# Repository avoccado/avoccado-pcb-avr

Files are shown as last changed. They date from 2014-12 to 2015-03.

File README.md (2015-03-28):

Avoccado° PCB layouts and schematics
================

**Most recent version: Avoccado° Felina**

This repository contains the source files of the PCBs for Avoccado° controllers equipped with AVR micro controllers.

There are different PCBs, some with more than one revision. Check the commit log for the most recent development version.

 - Alpha 1 (A1): 8/10 mil width/spacing, 2 sided, components on one side, full size rectangular board a la Arduino Nano / Pro Mini with female micro USB 2.0 and LiPo charger
 - Kane: 8/8 mil, small square board without LiPo charger, components on both sides, good as a tiny RX (receiver) node.
 - Yolandi: 8/8 mil, never tested
 - Nora 1: square board, about one square inch, IRQ from NRF24 routed to MCU
 - Nora 2: same as Nora 1 with IRQ from NRF24 and MPU6050 routed to MCU
 - Faye: updated Nora 2 with voltage divider to sense battery voltage and derive SOC (state of charge), added optional micro USB SMD socket on bottom layer, optionally less part diversity count as R_charge-program can be set with two serialised 1K 0402 resistors. Faye has got an equal 100 mil grid for every pin header and test point.
 - Felina: Features like Faye, without 0402 R_charge-program, non-square footprint, with MPU6050 QFN on board (optional), USB SMD on bottom layer
 - Gin: Board layout smaller than one NRF24L01 PCB module, features AtMega328 QFN + MPU6050 QFN. Not possible to hand solder, very small overall footprint. USB connector only passive (for charging)

Alpha 1 (A1):
----------------
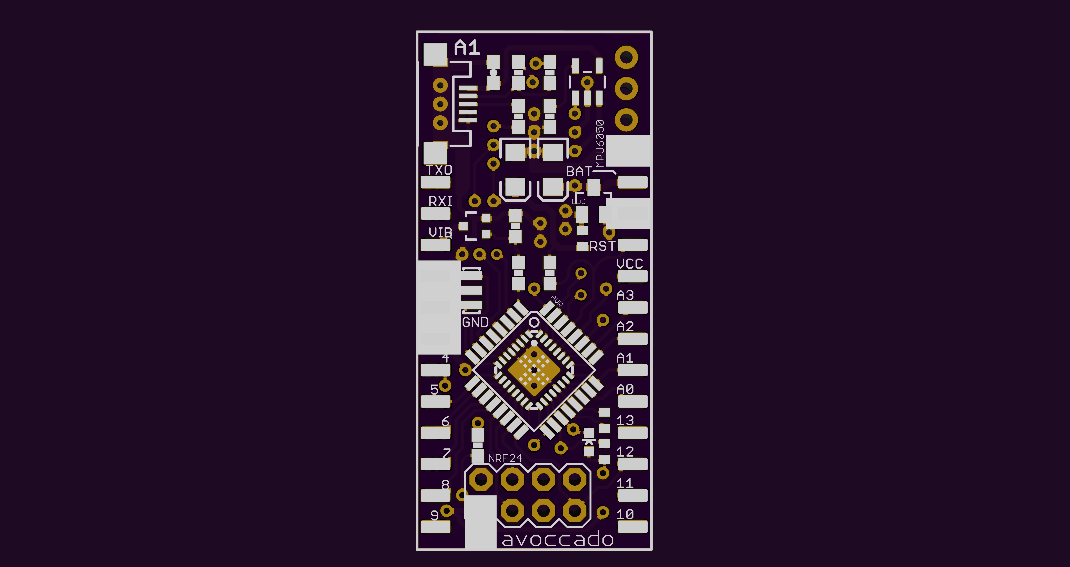
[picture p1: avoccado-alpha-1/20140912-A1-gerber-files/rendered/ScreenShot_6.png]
IMG board screenshot

USB bootloader option to update the firmware if the 68R resistors are populated. The USB data lines connect to D2 and D7.
There is a 2K pullup to 3.3V at the D- USB data line, no zener diodes to limit the voltage at the data lines because the MCU runs at USB compliant 3.3V VCC, see vUSB recommendations here: http://vusb.wikidot.com/hardware

Kane
----------------
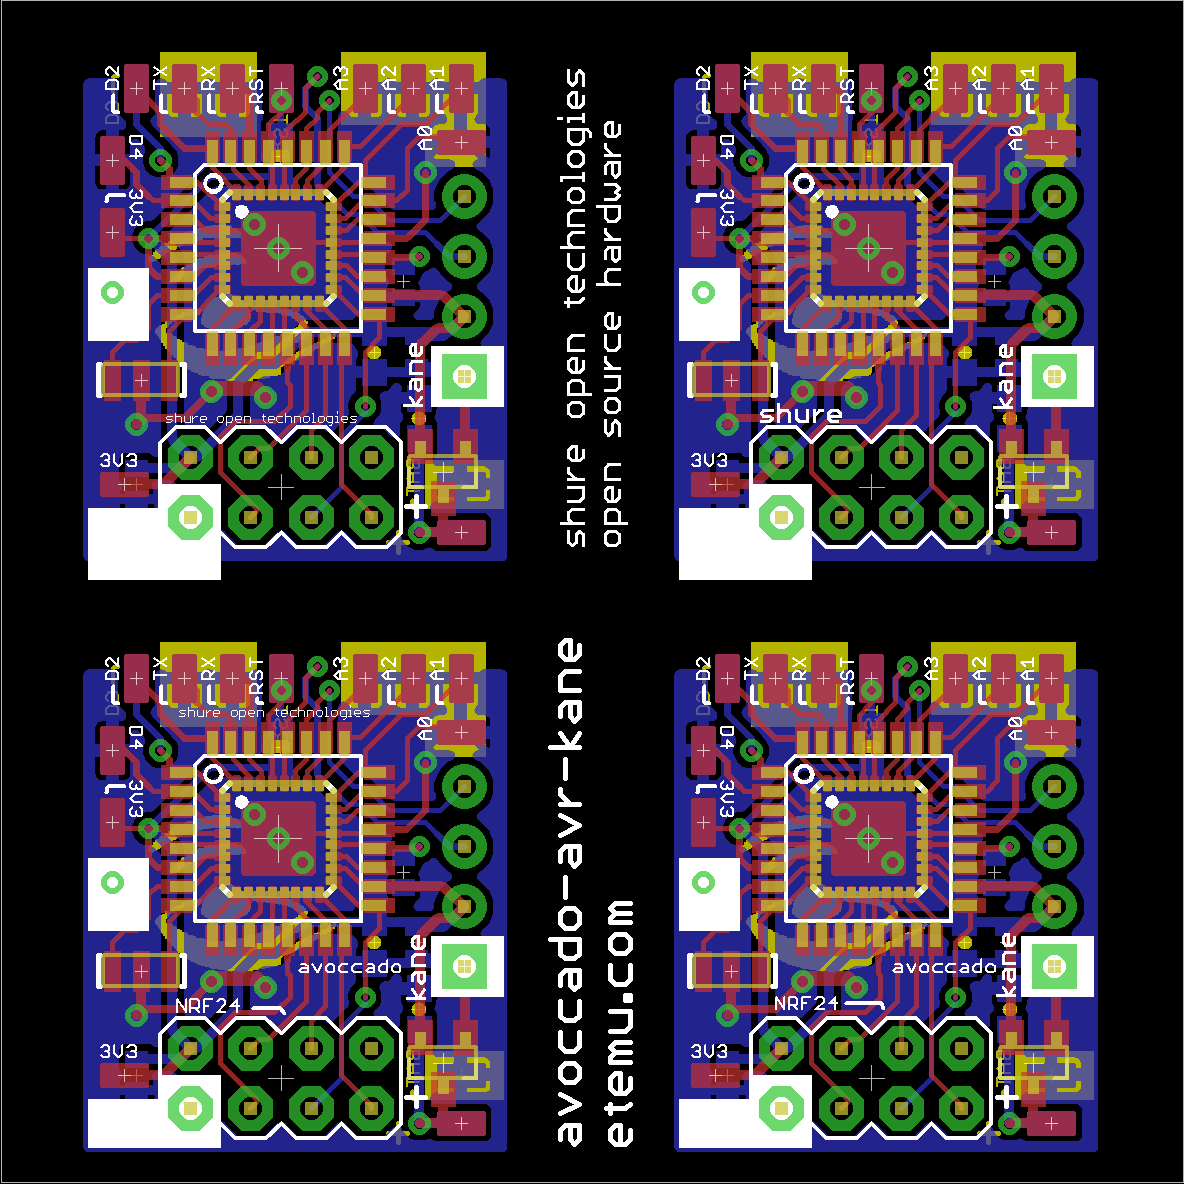
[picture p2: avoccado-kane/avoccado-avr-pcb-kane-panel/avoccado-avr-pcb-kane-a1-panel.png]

Smallest version when MPU6050 board not used. Hard to populate due to parts on both sides. Good for tiny receiver nodes, can be hidden in the E27 socket of a light bulb, wall socket..

Nora
----------------
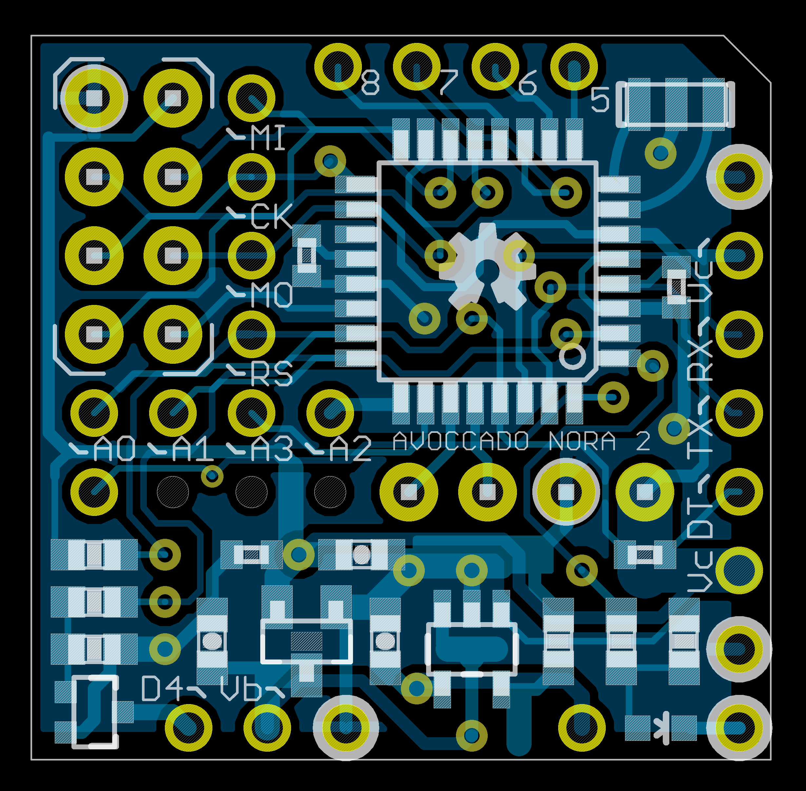
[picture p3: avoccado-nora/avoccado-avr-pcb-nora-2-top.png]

Notes and ideas: No cinsistent 100 mil grid with all headers at the moment
Plated half holes are nice for SMD piggybacking the hole board. Mind the test points and exposed pads on the bottom.

Faye
----------------
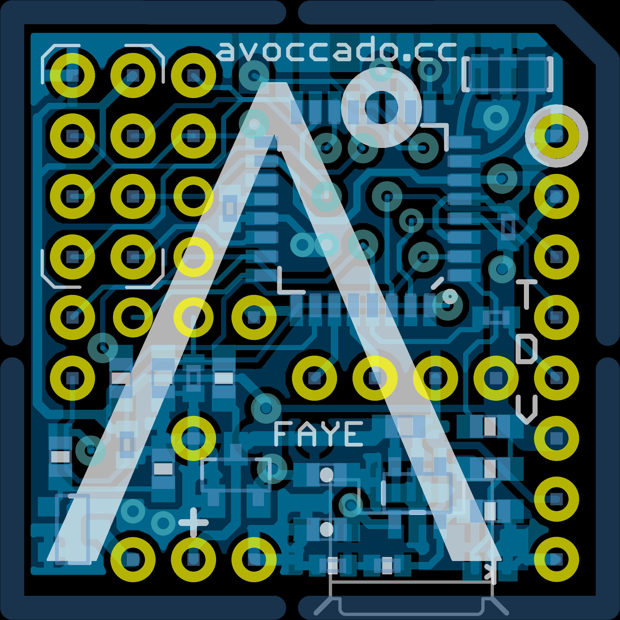
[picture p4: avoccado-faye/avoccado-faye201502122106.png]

Consistent 100 mil grid for all pin headers, additional test points (all conforming the 100 mil grid).
Tighter spacing with 0402 parts now close to the MCU and border of the board.
Battery voltage fed into ADC portpin through high impedance voltage divider to estimate SOC with the MCU.
Optional micro USB socket on the bottom. Data lines not used as of now due to routing constraints, only used for power and charging LiPo batteries.

Felina
----------------
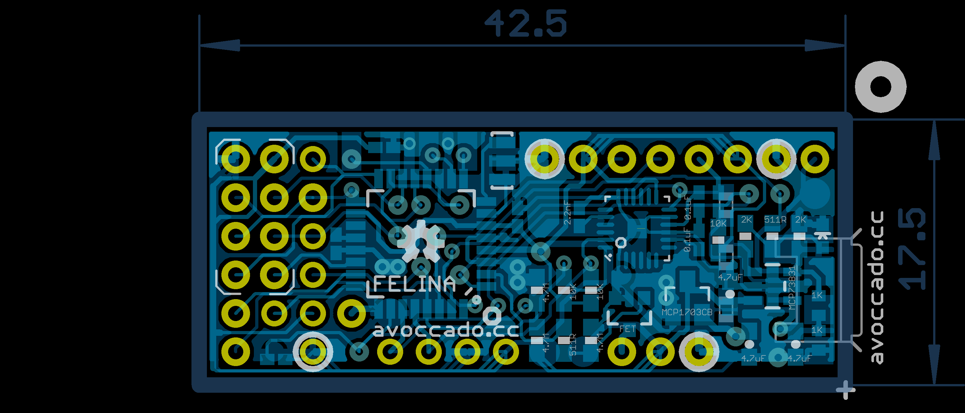
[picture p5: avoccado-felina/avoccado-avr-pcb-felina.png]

InvenSense MPU6000 / MPU6050 QFN package on board instead of peripheral daughter board. Header for peripheral board still available. Slim rectangular design, slightly longer due to additional parts for onboard MPU, thus only 10 PCBs per panel instead of the usual 16.
Battery voltage fed into ADC portpin through high impedance voltage divider to estimate SOC with the MCU.
Optional: Micro USB female on bottom side for charging
Optional: V-USB components with 2K pullup on D- to enable USB firmware usage. (needs airwire for one data line) 
Attention: V-USB uses same D2 IRQ line as MPU6050.
Consistent 100 mil grid for all pin headers, additional test points, SMD pad for vibration motor output.

Gin
----------------
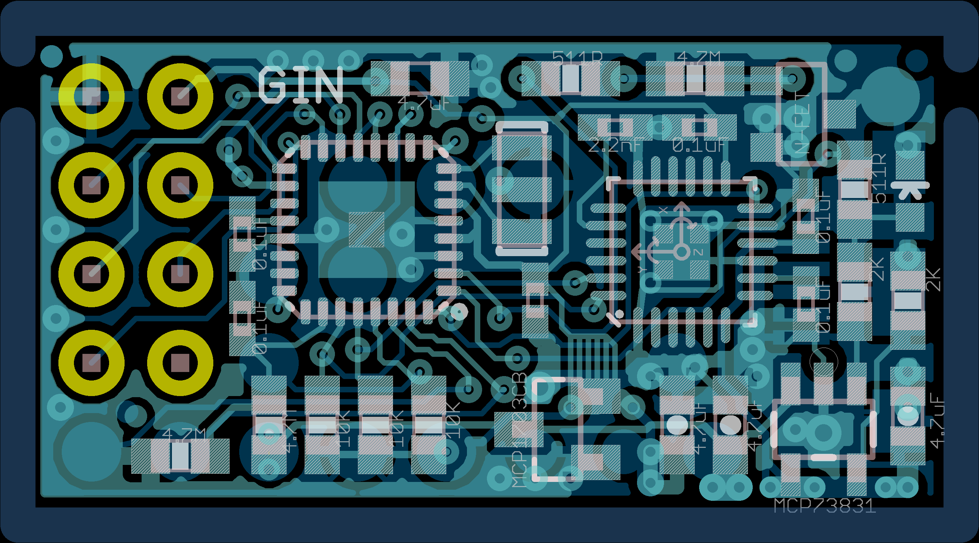
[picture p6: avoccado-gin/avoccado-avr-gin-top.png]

InvenSense MPU6050 QFN package, Atmel AtMega328p QFN package, very small overall footprint, smaller than a NRF24 module. No seperate ICSP header, flashing only via test points and the NRF24 connector. No DTR reset latch with capacitor.
Consistent 100 mil grid for all headers and test points. 

Panels 
----------------
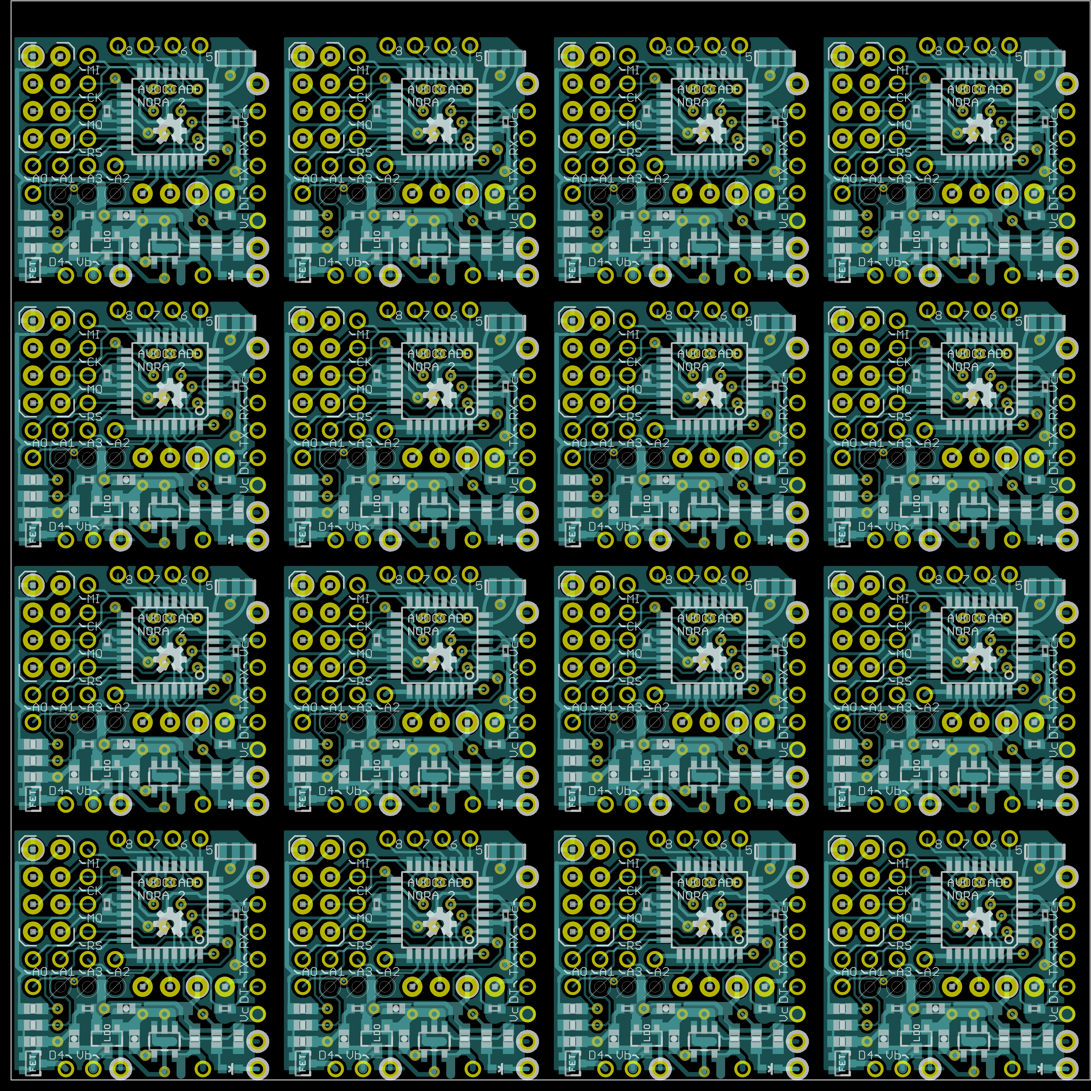
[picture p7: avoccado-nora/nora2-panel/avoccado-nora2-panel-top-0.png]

Boards are either panelized to 50 x 50 mm² or 100 x 100 mm² because my test jig can hold those two sizes. PCBs are usually placed on a 25 mm grid - that is slightly below one inch (25.4 mm).

Test jigs
----------------
Nora 2 test jig is compatible with Nora 1 and Nora 2
See separate repository for test jig assemblies

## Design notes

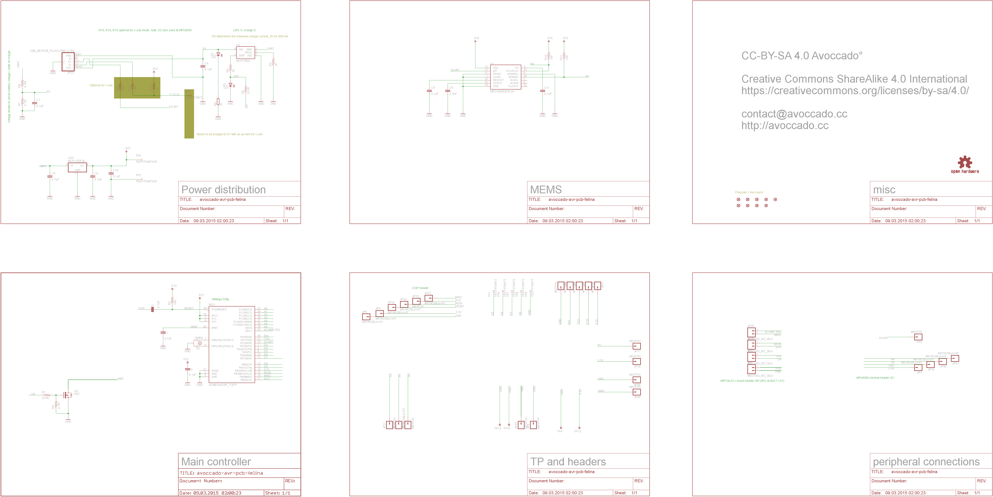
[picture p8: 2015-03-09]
avoccado-felina/avoccado-avr-pcb-felina-schematic.png

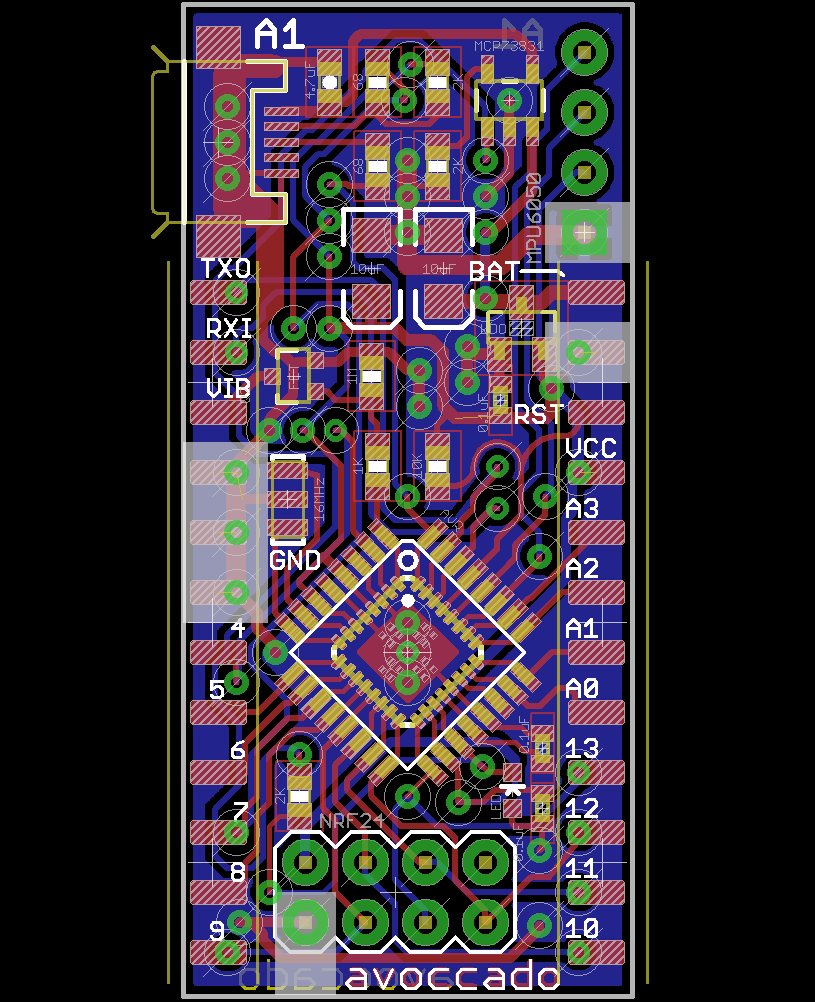
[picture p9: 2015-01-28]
avoccado-alpha-1/avoccado-avr-pcb.png

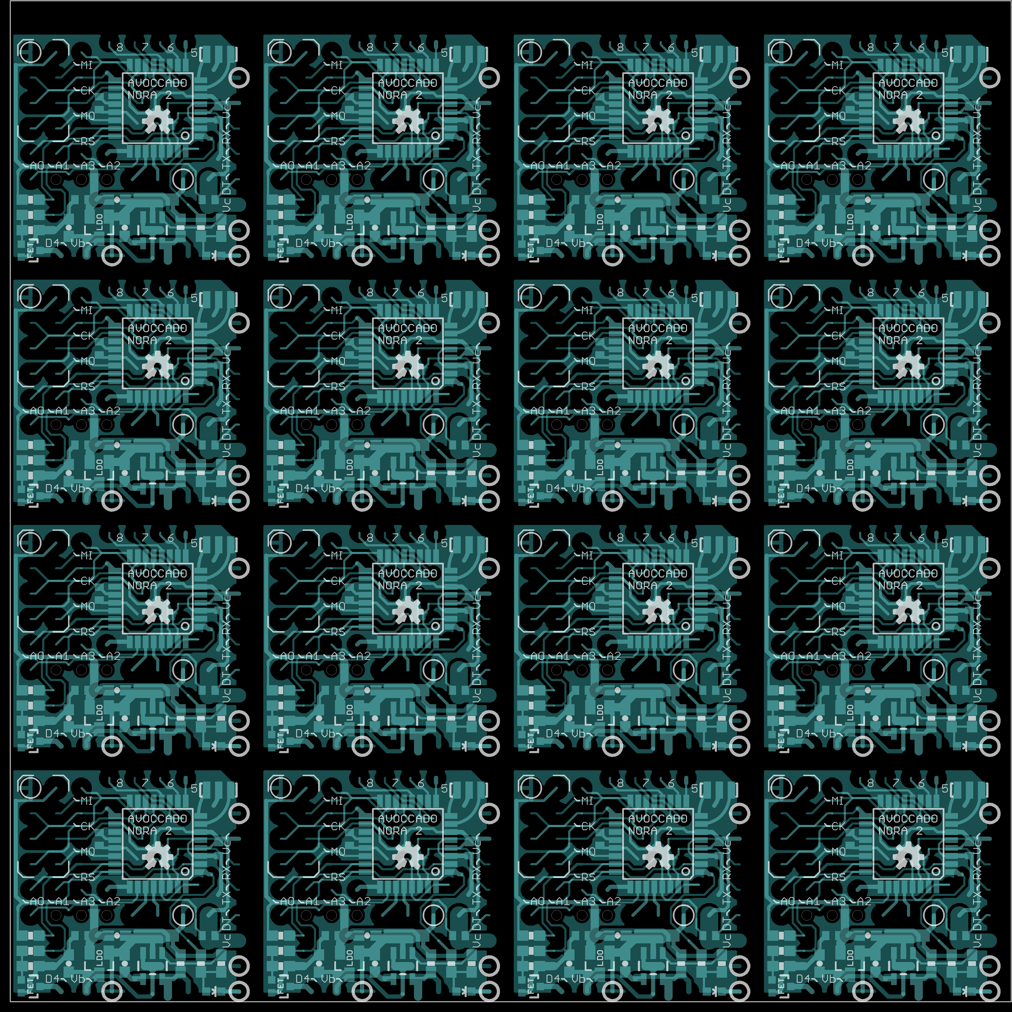
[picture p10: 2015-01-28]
avoccado-nora/nora2-panel/avoccado-nora2-panel-top-4.png

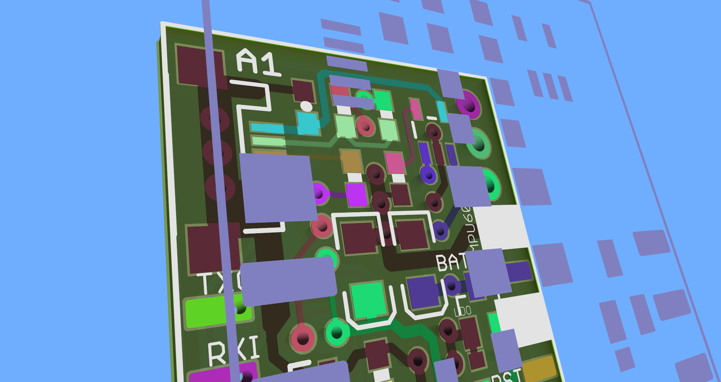
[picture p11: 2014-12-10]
avoccado-alpha-1/20140912-A1-gerber-files/rendered/ScreenShot_5.png

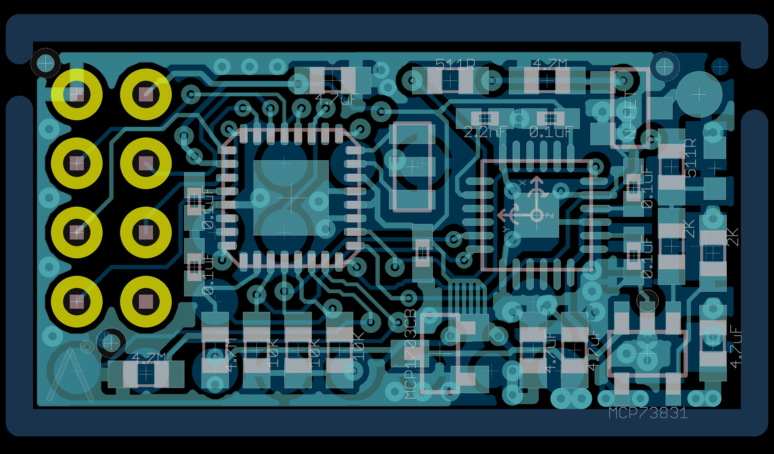
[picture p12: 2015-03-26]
avoccado-gin/avoccado-avr-gin-top-bot.png

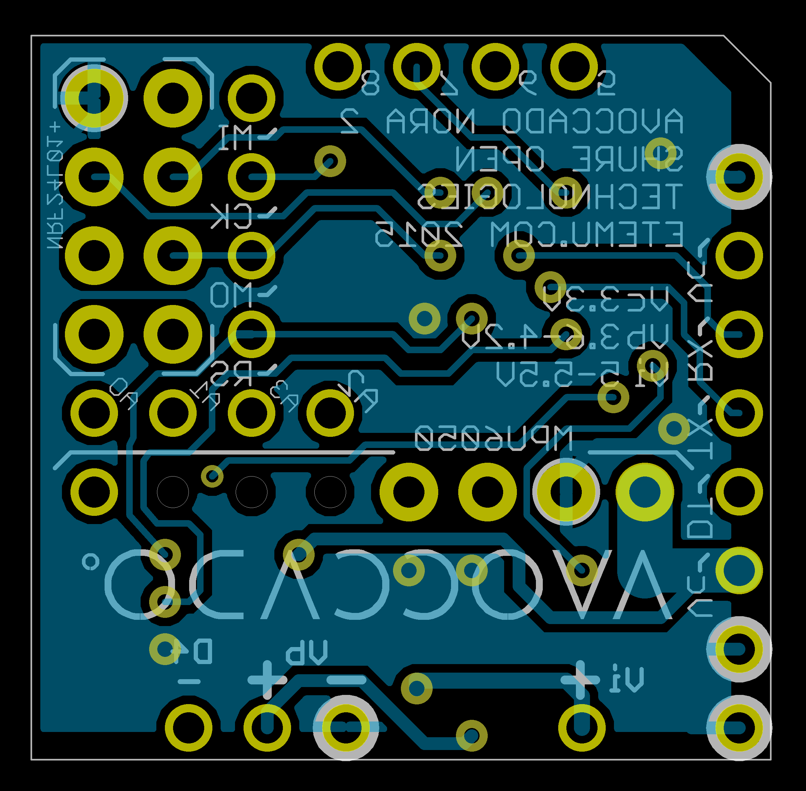
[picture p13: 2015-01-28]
avoccado-nora/avoccado-avr-pcb-nora-2-bot.png

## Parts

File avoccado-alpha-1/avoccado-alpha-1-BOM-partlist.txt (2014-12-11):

Partlist

Exported from avoccado-avr-pcb.brd at 12/8/2014 3:34:41 PM

Assembly variant: Full

Part     Value                   Package       Position (mil)        Orientation
                                               
C1       0.1uF                   C0402         (575 425)             R270
C3       0.1uF                   C0402         (575 325)             R90
C4       4.7uF                   0603-CAP      (220 1535)            R90
C10      0.1uF                   C0402         (505 1005)            R90
C13      10uF                    EIA3216       (290 1225)            R270
C19      10uF                    EIA3216       (410 1225)            R270
D1       CHARGE LED              LED-0603      (525 355)             R0
IC1      MCP1703CB               SOT23         (540 1125)            R0
JP1      4x1 header female       1X04_LOCK     (650 1285)            R90
NRF24    4X2 header female       2X4           (330 185)             R0
Q1       16MHz                   RESONATOR-SMD (150 840)             R90
Q2       MOSFET-NCHANNEL2N7002PW SOT323        (160 1045)            R90
R1       1K                      0603-RES      (300 895)             R90
R2       10K                     0603-RES      (400 895)             R90
R3       2K                      0603-RES      (400 1395)            R90
R4       2K                      0603-RES      (170 345)             R90
R5       1M                      0603-RES      (290 1045)            R270
R6       68                      0603-RES      (300 1535)            R90
R7       68                      0603-RES      (300 1395)            R270
R8       2K                      0603-RES      (400 1535)            R90
U2       MCP73831                SOT23-5       (520 1505)            R0
X1       Micro USB               USB-MICROB    (50 1435)             R270

and either of the following two:
IC5      ATMEGA328P-20MU         MLF32         (350 585)             R315
U1       ATMEGA328P              TQFP32-08     (350 585)             R315

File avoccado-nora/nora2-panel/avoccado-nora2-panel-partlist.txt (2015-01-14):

Partlist

Exported from avoccado-nora2-panel-100x100.brd

EAGLE Version 7.2.0 Copyright (c) 1988-2014 CadSoft

Assembly variant: 

Part     Value           Package       Library               Position (inch)       Orientation

AVR      ATMEGA328P      TQFP32-08     SparkFun-DigitalIC    (0.58 0.62031496)     R180
AVR1     ATMEGA328P      TQFP32-08     SparkFun-DigitalIC    (1.56425197 0.62031496) R180
AVR2     ATMEGA328P      TQFP32-08     SparkFun-DigitalIC    (0.58 1.58488189)     R180
AVR3     ATMEGA328P      TQFP32-08     SparkFun-DigitalIC    (1.56425197 1.58488189) R180
AVR4     ATMEGA328P      TQFP32-08     SparkFun-DigitalIC    (2.54850394 0.62031496) R180
AVR5     ATMEGA328P      TQFP32-08     SparkFun-DigitalIC    (3.53275591 0.62031496) R180
AVR6     ATMEGA328P      TQFP32-08     SparkFun-DigitalIC    (2.54850394 1.58488189) R180
AVR7     ATMEGA328P      TQFP32-08     SparkFun-DigitalIC    (3.53275591 1.58488189) R180
AVR8     ATMEGA328P      TQFP32-08     SparkFun-DigitalIC    (0.58 2.54944882)     R180
AVR9     ATMEGA328P      TQFP32-08     SparkFun-DigitalIC    (1.56425197 2.54944882) R180
AVR10    ATMEGA328P      TQFP32-08     SparkFun-DigitalIC    (0.58 3.51401575)     R180
AVR11    ATMEGA328P      TQFP32-08     SparkFun-DigitalIC    (1.56425197 3.51401575) R180
AVR12    ATMEGA328P      TQFP32-08     SparkFun-DigitalIC    (2.54850394 2.54944882) R180
AVR13    ATMEGA328P      TQFP32-08     SparkFun-DigitalIC    (3.53275591 2.54944882) R180
AVR14    ATMEGA328P      TQFP32-08     SparkFun-DigitalIC    (2.54850394 3.51401575) R180
AVR15    ATMEGA328P      TQFP32-08     SparkFun-DigitalIC    (3.53275591 3.51401575) R180
C1       0.1uF           C0402         SparkFun              (0.35 0.64031496)     R90
C2       0.1uF           C0402         SparkFun              (0.78 0.26031496)     R0
C3       0.1uF           C0402         SparkFun              (0.82 0.60031496)     R90
C4       4.7uF           0603-CAP      SparkFun-Capacitors   (0.45 0.15031496)     R90
C5       4.7uF           0603-CAP      SparkFun-Capacitors   (0.23 0.15031496)     R90
C6       4.7uF           0603-CAP      SparkFun-Capacitors   (0.42 0.26031496)     R0
C7       0.1uF           C0402         SparkFun              (1.26425197 0.26031496) R180
C8       0.1uF           C0402         SparkFun              (1.80425197 0.60031496) R90
C9       0.1uF           C0402         SparkFun              (1.33425197 0.64031496) R90
C10      0.1uF           C0402         SparkFun              (0.28 0.26031496)     R180
C11      4.7uF           0603-CAP      SparkFun-Capacitors   (1.43425197 0.15031496) R90
C12      0.1uF           C0402         SparkFun              (1.76425197 0.26031496) R0
C13      4.7uF           0603-CAP      SparkFun-Capacitors   (1.21425197 0.15031496) R90
C14      4.7uF           0603-CAP      SparkFun-Capacitors   (1.40425197 0.26031496) R0
C15      0.1uF           C0402         SparkFun              (0.28 1.22488189)     R180
C16      0.1uF           C0402         SparkFun              (0.82 1.56488189)     R90
C17      0.1uF           C0402         SparkFun              (0.35 1.60488189)     R90
C18      4.7uF           0603-CAP      SparkFun-Capacitors   (0.45 1.11488189)     R90
C19      0.1uF           C0402         SparkFun              (0.78 1.22488189)     R0
C20      4.7uF           0603-CAP      SparkFun-Capacitors   (0.23 1.11488189)     R90
C21      4.7uF           0603-CAP      SparkFun-Capacitors   (0.42 1.22488189)     R0
C22      0.1uF           C0402         SparkFun              (1.26425197 1.22488189) R180
C23      0.1uF           C0402         SparkFun              (1.80425197 1.56488189) R90
C24      0.1uF           C0402         SparkFun              (1.33425197 1.60488189) R90
C25      4.7uF           0603-CAP      SparkFun-Capacitors   (1.43425197 1.11488189) R90
C26      0.1uF           C0402         SparkFun              (1.76425197 1.22488189) R0
C27      4.7uF           0603-CAP      SparkFun-Capacitors   (1.21425197 1.11488189) R90
C28      4.7uF           0603-CAP      SparkFun-Capacitors   (1.40425197 1.22488189) R0
C29      0.1uF           C0402         SparkFun              (2.24850394 0.26031496) R180
C30      0.1uF           C0402         SparkFun              (2.78850394 0.60031496) R90
C31      0.1uF           C0402         SparkFun              (2.31850394 0.64031496) R90
C32      4.7uF           0603-CAP      SparkFun-Capacitors   (2.41850394 0.15031496) R90
C33      0.1uF           C0402         SparkFun              (2.74850394 0.26031496) R0
C34      4.7uF           0603-CAP      SparkFun-Capacitors   (2.19850394 0.15031496) R90
C35      4.7uF           0603-CAP      SparkFun-Capacitors   (2.38850394 0.26031496) R0
C36      0.1uF           C0402         SparkFun              (3.23275591 0.26031496) R180
C37      0.1uF           C0402         SparkFun              (3.77275591 0.60031496) R90
C38      0.1uF           C0402         SparkFun              (3.30275591 0.64031496) R90
C39      4.7uF           0603-CAP      SparkFun-Capacitors   (3.40275591 0.15031496) R90
C40      0.1uF           C0402         SparkFun              (3.73275591 0.26031496) R0
C41      4.7uF           0603-CAP      SparkFun-Capacitors   (3.18275591 0.15031496) R90
C42      4.7uF           0603-CAP      SparkFun-Capacitors   (3.37275591 0.26031496) R0
C43      0.1uF           C0402         SparkFun              (2.24850394 1.22488189) R180
C44      0.1uF           C0402         SparkFun              (2.78850394 1.56488189) R90
C45      0.1uF           C0402         SparkFun              (2.31850394 1.60488189) R90
C46      4.7uF           0603-CAP      SparkFun-Capacitors   (2.41850394 1.11488189) R90
C47      0.1uF           C0402         SparkFun              (2.74850394 1.22488189) R0
C48      4.7uF           0603-CAP      SparkFun-Capacitors   (2.19850394 1.11488189) R90
C49      4.7uF           0603-CAP      SparkFun-Capacitors   (2.38850394 1.22488189) R0
C50      0.1uF           C0402         SparkFun              (3.23275591 1.22488189) R180
C51      0.1uF           C0402         SparkFun              (3.77275591 1.56488189) R90
C52      0.1uF           C0402         SparkFun              (3.30275591 1.60488189) R90
C53      4.7uF           0603-CAP      SparkFun-Capacitors   (3.40275591 1.11488189) R90
C54      0.1uF           C0402         SparkFun              (3.73275591 1.22488189) R0
C55      4.7uF           0603-CAP      SparkFun-Capacitors   (3.18275591 1.11488189) R90
C56      4.7uF           0603-CAP      SparkFun-Capacitors   (3.37275591 1.22488189) R0
C57      0.1uF           C0402         SparkFun              (0.28 2.18944882)     R180
C58      0.1uF           C0402         SparkFun              (0.82 2.52944882)     R90
C59      0.1uF           C0402         SparkFun              (0.35 2.56944882)     R90
C60      4.7uF           0603-CAP      SparkFun-Capacitors   (0.45 2.07944882)     R90
C61      0.1uF           C0402         SparkFun              (0.78 2.18944882)     R0
C62      4.7uF           0603-CAP      SparkFun-Capacitors   (0.23 2.07944882)     R90
C63      4.7uF           0603-CAP      SparkFun-Capacitors   (0.42 2.18944882)     R0
C64      0.1uF           C0402         SparkFun              (1.26425197 2.18944882) R180
C65      0.1uF           C0402         SparkFun              (1.80425197 2.52944882) R90
C66      0.1uF           C0402         SparkFun              (1.33425197 2.56944882) R90
C67      4.7uF           0603-CAP      SparkFun-Capacitors   (1.43425197 2.07944882) R90
C68      0.1uF           C0402         SparkFun              (1.76425197 2.18944882) R0
C69      4.7uF           0603-CAP      SparkFun-Capacitors   (1.21425197 2.07944882) R90
C70      4.7uF           0603-CAP      SparkFun-Capacitors   (1.40425197 2.18944882) R0
C71      0.1uF           C0402         SparkFun              (0.28 3.15401575)     R180
C72      0.1uF           C0402         SparkFun              (0.82 3.49401575)     R90
C73      0.1uF           C0402         SparkFun              (0.35 3.53401575)     R90
C74      4.7uF           0603-CAP      SparkFun-Capacitors   (0.45 3.04401575)     R90
C75      0.1uF           C0402         SparkFun              (0.78 3.15401575)     R0
C76      4.7uF           0603-CAP      SparkFun-Capacitors   (0.23 3.04401575)     R90
C77      4.7uF           0603-CAP      SparkFun-Capacitors   (0.42 3.15401575)     R0
C78      0.1uF           C0402         SparkFun              (1.26425197 3.15401575) R180
C79      0.1uF           C0402         SparkFun              (1.80425197 3.49401575) R90
C80      0.1uF           C0402         SparkFun              (1.33425197 3.53401575) R90
C81      4.7uF           0603-CAP      SparkFun-Capacitors   (1.43425197 3.04401575) R90
C82      0.1uF           C0402         SparkFun              (1.76425197 3.15401575) R0
C83      4.7uF           0603-CAP      SparkFun-Capacitors   (1.21425197 3.04401575) R90
C84      4.7uF           0603-CAP      SparkFun-Capacitors   (1.40425197 3.15401575) R0
C85      0.1uF           C0402         SparkFun              (2.24850394 2.18944882) R180
C86      0.1uF           C0402         SparkFun              (2.78850394 2.52944882) R90
C87      0.1uF           C0402         SparkFun              (2.31850394 2.56944882) R90
C88      4.7uF           0603-CAP      SparkFun-Capacitors   (2.41850394 2.07944882) R90
C89      0.1uF           C0402         SparkFun              (2.74850394 2.18944882) R0
C90      4.7uF           0603-CAP      SparkFun-Capacitors   (2.19850394 2.07944882) R90
C91      4.7uF           0603-CAP      SparkFun-Capacitors   (2.38850394 2.18944882) R0
C92      0.1uF           C0402         SparkFun              (3.23275591 2.18944882) R180
C93      0.1uF           C0402         SparkFun              (3.77275591 2.52944882) R90
C94      0.1uF           C0402         SparkFun              (3.30275591 2.56944882) R90
C95      4.7uF           0603-CAP      SparkFun-Capacitors   (3.40275591 2.07944882) R90
C96      0.1uF           C0402         SparkFun              (3.73275591 2.18944882) R0
C97      4.7uF           0603-CAP      SparkFun-Capacitors   (3.18275591 2.07944882) R90
C98      4.7uF           0603-CAP      SparkFun-Capacitors   (3.37275591 2.18944882) R0
C99      0.1uF           C0402         SparkFun              (2.24850394 3.15401575) R180
C100     0.1uF           C0402         SparkFun              (2.78850394 3.49401575) R90
C101     0.1uF           C0402         SparkFun              (2.31850394 3.53401575) R90
C102     4.7uF           0603-CAP      SparkFun-Capacitors   (2.41850394 3.04401575) R90
C103     0.1uF           C0402         SparkFun              (2.74850394 3.15401575) R0
C104     4.7uF           0603-CAP      SparkFun-Capacitors   (2.19850394 3.04401575) R90
C105     4.7uF           0603-CAP      SparkFun-Capacitors   (2.38850394 3.15401575) R0
C106     0.1uF           C0402         SparkFun              (3.23275591 3.15401575) R180
C107     0.1uF           C0402         SparkFun              (3.77275591 3.49401575) R90
C108     0.1uF           C0402         SparkFun              (3.30275591 3.53401575) R90
C109     4.7uF           0603-CAP      SparkFun-Capacitors   (3.40275591 3.04401575) R90
C110     0.1uF           C0402         SparkFun              (3.73275591 3.15401575) R0
C111     4.7uF           0603-CAP      SparkFun-Capacitors   (3.18275591 3.04401575) R90
C112     4.7uF           0603-CAP      SparkFun-Capacitors   (3.37275591 3.15401575) R0
D1       LED             LED-0603      SparkFun              (0.80031496 0.04)     R270
D2       LED             LED-0603      SparkFun              (1.78456693 0.04)     R270
D3       LED             LED-0603      SparkFun              (0.80031496 1.00456693) R270
D4       LED             LED-0603      SparkFun              (1.78456693 1.00456693) R270
D5       LED             LED-0603      SparkFun              (2.7688189 0.04)      R270
D6       LED             LED-0603      SparkFun              (3.75307087 0.04)     R270
D7       LED             LED-0603      SparkFun              (2.7688189 1.00456693) R270
D8       LED             LED-0603      SparkFun              (3.75307087 1.00456693) R270
D9       LED             LED-0603      SparkFun              (0.80031496 1.96913386) R270
D10      LED             LED-0603      SparkFun              (1.78456693 1.96913386) R270
D11      LED             LED-0603      SparkFun              (0.80031496 2.93370079) R270
D12      LED             LED-0603      SparkFun              (1.78456693 2.93370079) R270
D13      LED             LED-0603      SparkFun              (2.7688189 1.96913386) R270
D14      LED             LED-0603      SparkFun              (3.75307087 1.96913386) R270
D15      LED             LED-0603      SparkFun              (2.7688189 2.93370079) R270
D16      LED             LED-0603      SparkFun              (3.75307087 2.93370079) R270
LDO      MCP1703CB       SOT23         linear                (0.35 0.15031496)     R180
LDO1     MCP1703CB       SOT23         linear                (1.33425197 0.15031496) R180
LDO2     MCP1703CB       SOT23         linear                (0.35 1.11488189)     R180
LDO3     MCP1703CB       SOT23         linear                (1.33425197 1.11488189) R180
LDO4     MCP1703CB       SOT23         linear                (2.31850394 0.15031496) R180
LDO5     MCP1703CB       SOT23         linear                (3.30275591 0.15031496) R180
LDO6     MCP1703CB       SOT23         linear                (2.31850394 1.11488189) R180
LDO7     MCP1703CB       SOT23         linear                (3.30275591 1.11488189) R180
LDO8     MCP1703CB       SOT23         linear                (0.35 2.07944882)     R180
LDO9     MCP1703CB       SOT23         linear                (1.33425197 2.07944882) R180
LDO10    MCP1703CB       SOT23         linear                (0.35 3.04401575)     R180
LDO11    MCP1703CB       SOT23         linear                (1.33425197 3.04401575) R180
LDO12    MCP1703CB       SOT23         linear                (2.31850394 2.07944882) R180
LDO13    MCP1703CB       SOT23         linear                (3.30275591 2.07944882) R180
LDO14    MCP1703CB       SOT23         linear                (2.31850394 3.04401575) R180
LDO15    MCP1703CB       SOT23         linear                (3.30275591 3.04401575) R180
Q1       16MHz           RESONATOR-SMD SparkFun              (0.82 0.83231496)     R0
Q2       FET             SOT323        SparkFun-DiscreteSemi (0.08 0.06031496)     R270
Q3       16MHz           RESONATOR-SMD SparkFun              (1.80425197 0.83231496) R0
Q4       FET             SOT323        SparkFun-DiscreteSemi (1.06425197 0.06031496) R270
Q5       16MHz           RESONATOR-SMD SparkFun              (0.82 1.79688189)     R0
Q6       FET             SOT323        SparkFun-DiscreteSemi (0.08 1.02488189)     R270
Q7       16MHz           RESONATOR-SMD SparkFun              (1.80425197 1.79688189) R0
Q8       FET             SOT323        SparkFun-DiscreteSemi (1.06425197 1.02488189) R270
Q9       16MHz           RESONATOR-SMD SparkFun              (2.78850394 0.83231496) R0
Q10      FET             SOT323        SparkFun-DiscreteSemi (2.04850394 0.06031496) R270
Q11      16MHz           RESONATOR-SMD SparkFun              (3.77275591 0.83231496) R0
Q12      FET             SOT323        SparkFun-DiscreteSemi (3.03275591 0.06031496) R270
Q13      16MHz           RESONATOR-SMD SparkFun              (2.78850394 1.79688189) R0
Q14      FET             SOT323        SparkFun-DiscreteSemi (2.04850394 1.02488189) R270
Q15      16MHz           RESONATOR-SMD SparkFun              (3.77275591 1.79688189) R0
Q16      FET             SOT323        SparkFun-DiscreteSemi (3.03275591 1.02488189) R270
Q17      16MHz           RESONATOR-SMD SparkFun              (0.82 2.76144882)     R0
Q18      FET             SOT323        SparkFun-DiscreteSemi (0.08 1.98944882)     R270
Q19      16MHz           RESONATOR-SMD SparkFun              (1.80425197 2.76144882) R0
Q20      FET             SOT323        SparkFun-DiscreteSemi (1.06425197 1.98944882) R270
Q21      16MHz           RESONATOR-SMD SparkFun              (0.82 3.72601575)     R0
Q22      FET             SOT323        SparkFun-DiscreteSemi (0.08 2.95401575)     R270
Q23      16MHz           RESONATOR-SMD SparkFun              (1.80425197 3.72601575) R0
Q24      FET             SOT323        SparkFun-DiscreteSemi (1.06425197 2.95401575) R270
Q25      16MHz           RESONATOR-SMD SparkFun              (2.78850394 2.76144882) R0
Q26      FET             SOT323        SparkFun-DiscreteSemi (2.04850394 1.98944882) R270
Q27      16MHz           RESONATOR-SMD SparkFun              (3.77275591 2.76144882) R0
Q28      FET             SOT323        SparkFun-DiscreteSemi (3.03275591 1.98944882) R270
Q29      16MHz           RESONATOR-SMD SparkFun              (2.78850394 3.72601575) R0
Q30      FET             SOT323        SparkFun-DiscreteSemi (2.04850394 2.95401575) R270
Q31      16MHz           RESONATOR-SMD SparkFun              (3.77275591 3.72601575) R0
Q32      FET             SOT323        SparkFun-DiscreteSemi (3.03275591 2.95401575) R270
R1       1K              0603-RES      SparkFun-Resistors    (0.08 0.20031496)     R180
R2       10K             0603-RES      SparkFun-Resistors    (0.08 0.26031496)     R180
R3       2K              0603-RES      SparkFun-Resistors    (0.67 0.15031496)     R270
R4       1K              0603-RES      SparkFun-Resistors    (0.83 0.15031496)     R90
R5       1M              0603-RES      SparkFun-Resistors    (0.08 0.14031496)     R180
R6       1K              0603-RES      SparkFun-Resistors    (0.75 0.15031496)     R270
R7       10K             0603-RES      SparkFun-Resistors    (1.06425197 0.26031496) R180
R8       1K              0603-RES      SparkFun-Resistors    (1.06425197 0.20031496) R180
R9       2K              0603-RES      SparkFun-Resistors    (1.65425197 0.15031496) R270
R10      1K              0603-RES      SparkFun-Resistors    (1.81425197 0.15031496) R90
R11      1M              0603-RES      SparkFun-Resistors    (1.06425197 0.14031496) R180
R12      1K              0603-RES      SparkFun-Resistors    (1.73425197 0.15031496) R270
R13      10K             0603-RES      SparkFun-Resistors    (0.08 1.22488189)     R180
R14      1K              0603-RES      SparkFun-Resistors    (0.08 1.16488189)     R180
R15      2K              0603-RES      SparkFun-Resistors    (0.67 1.11488189)     R270
R16      1K              0603-RES      SparkFun-Resistors    (0.83 1.11488189)     R90
R17      1M              0603-RES      SparkFun-Resistors    (0.08 1.10488189)     R180
R18      1K              0603-RES      SparkFun-Resistors    (0.75 1.11488189)     R270
R19      10K             0603-RES      SparkFun-Resistors    (1.06425197 1.22488189) R180
R20      1K              0603-RES      SparkFun-Resistors    (1.06425197 1.16488189) R180
R21      2K              0603-RES      SparkFun-Resistors    (1.65425197 1.11488189) R270
R22      1K              0603-RES      SparkFun-Resistors    (1.81425197 1.11488189) R90
R23      1M              0603-RES      SparkFun-Resistors    (1.06425197 1.10488189) R180
R24      1K              0603-RES      SparkFun-Resistors    (1.73425197 1.11488189) R270
R25      10K             0603-RES      SparkFun-Resistors    (2.04850394 0.26031496) R180
R26      1K              0603-RES      SparkFun-Resistors    (2.04850394 0.20031496) R180
R27      2K              0603-RES      SparkFun-Resistors    (2.63850394 0.15031496) R270
R28      1K              0603-RES      SparkFun-Resistors    (2.79850394 0.15031496) R90
R29      1M              0603-RES      SparkFun-Resistors    (2.04850394 0.14031496) R180
R30      1K              0603-RES      SparkFun-Resistors    (2.71850394 0.15031496) R270
R31      10K             0603-RES      SparkFun-Resistors    (3.03275591 0.26031496) R180
R32      1K              0603-RES      SparkFun-Resistors    (3.03275591 0.20031496) R180
R33      2K              0603-RES      SparkFun-Resistors    (3.62275591 0.15031496) R270
R34      1K              0603-RES      SparkFun-Resistors    (3.78275591 0.15031496) R90
R35      1M              0603-RES      SparkFun-Resistors    (3.03275591 0.14031496) R180
R36      1K              0603-RES      SparkFun-Resistors    (3.70275591 0.15031496) R270
R37      10K             0603-RES      SparkFun-Resistors    (2.04850394 1.22488189) R180
R38      1K              0603-RES      SparkFun-Resistors    (2.04850394 1.16488189) R180
R39      2K              0603-RES      SparkFun-Resistors    (2.63850394 1.11488189) R270
R40      1K              0603-RES      SparkFun-Resistors    (2.79850394 1.11488189) R90
R41      1M              0603-RES      SparkFun-Resistors    (2.04850394 1.10488189) R180
R42      1K              0603-RES      SparkFun-Resistors    (2.71850394 1.11488189) R270
R43      10K             0603-RES      SparkFun-Resistors    (3.03275591 1.22488189) R180
R44      1K              0603-RES      SparkFun-Resistors    (3.03275591 1.16488189) R180
R45      2K              0603-RES      SparkFun-Resistors    (3.62275591 1.11488189) R270
R46      1K              0603-RES      SparkFun-Resistors    (3.78275591 1.11488189) R90
R47      1M              0603-RES      SparkFun-Resistors    (3.03275591 1.10488189) R180
R48      1K              0603-RES      SparkFun-Resistors    (3.70275591 1.11488189) R270
R49      10K             0603-RES      SparkFun-Resistors    (0.08 2.18944882)     R180
R50      1K              0603-RES      SparkFun-Resistors    (0.08 2.12944882)     R180
R51      2K              0603-RES      SparkFun-Resistors    (0.67 2.07944882)     R270
R52      1K              0603-RES      SparkFun-Resistors    (0.83 2.07944882)     R90
R53      1M              0603-RES      SparkFun-Resistors    (0.08 2.06944882)     R180
R54      1K              0603-RES      SparkFun-Resistors    (0.75 2.07944882)     R270
R55      10K             0603-RES      SparkFun-Resistors    (1.06425197 2.18944882) R180
R56      1K              0603-RES      SparkFun-Resistors    (1.06425197 2.12944882) R180
R57      2K              0603-RES      SparkFun-Resistors    (1.65425197 2.07944882) R270
R58      1K              0603-RES      SparkFun-Resistors    (1.81425197 2.07944882) R90
R59      1M              0603-RES      SparkFun-Resistors    (1.06425197 2.06944882) R180
R60      1K              0603-RES      SparkFun-Resistors    (1.73425197 2.07944882) R270
R61      10K             0603-RES      SparkFun-Resistors    (0.08 3.15401575)     R180
R62      1K              0603-RES      SparkFun-Resistors    (0.08 3.09401575)     R180
R63      2K              0603-RES      SparkFun-Resistors    (0.67 3.04401575)     R270
R64      1K              0603-RES      SparkFun-Resistors    (0.83 3.04401575)     R90
R65      1M              0603-RES      SparkFun-Resistors    (0.08 3.03401575)     R180
R66      1K              0603-RES      SparkFun-Resistors    (0.75 3.04401575)     R270
R67      10K             0603-RES      SparkFun-Resistors    (1.06425197 3.15401575) R180
R68      1K              0603-RES      SparkFun-Resistors    (1.06425197 3.09401575) R180
R69      2K              0603-RES      SparkFun-Resistors    (1.65425197 3.04401575) R270
R70      1K              0603-RES      SparkFun-Resistors    (1.81425197 3.04401575) R90
R71      1M              0603-RES      SparkFun-Resistors    (1.06425197 3.03401575) R180
R72      1K              0603-RES      SparkFun-Resistors    (1.73425197 3.04401575) R270
R73      10K             0603-RES      SparkFun-Resistors    (2.04850394 2.18944882) R180
R74      1K              0603-RES      SparkFun-Resistors    (2.04850394 2.12944882) R180
R75      2K              0603-RES      SparkFun-Resistors    (2.63850394 2.07944882) R270
R76      1K              0603-RES      SparkFun-Resistors    (2.79850394 2.07944882) R90
R77      1M              0603-RES      SparkFun-Resistors    (2.04850394 2.06944882) R180
R78      1K              0603-RES      SparkFun-Resistors    (2.71850394 2.07944882) R270
R79      10K             0603-RES      SparkFun-Resistors    (3.03275591 2.18944882) R180
R80      1K              0603-RES      SparkFun-Resistors    (3.03275591 2.12944882) R180
R81      2K              0603-RES      SparkFun-Resistors    (3.62275591 2.07944882) R270
R82      1K              0603-RES      SparkFun-Resistors    (3.78275591 2.07944882) R90
R83      1M              0603-RES      SparkFun-Resistors    (3.03275591 2.06944882) R180
R84      1K              0603-RES      SparkFun-Resistors    (3.70275591 2.07944882) R270
R85      10K             0603-RES      SparkFun-Resistors    (2.04850394 3.15401575) R180
R86      1K              0603-RES      SparkFun-Resistors    (2.04850394 3.09401575) R180
R87      2K              0603-RES      SparkFun-Resistors    (2.63850394 3.04401575) R270
R88      1K              0603-RES      SparkFun-Resistors    (2.79850394 3.04401575) R90
R89      1M              0603-RES      SparkFun-Resistors    (2.04850394 3.03401575) R180
R90      1K              0603-RES      SparkFun-Resistors    (2.71850394 3.04401575) R270
R91      10K             0603-RES      SparkFun-Resistors    (3.03275591 3.15401575) R180
R92      1K              0603-RES      SparkFun-Resistors    (3.03275591 3.09401575) R180
R93      2K              0603-RES      SparkFun-Resistors    (3.62275591 3.04401575) R270
R94      1K              0603-RES      SparkFun-Resistors    (3.78275591 3.04401575) R90
R95      1M              0603-RES      SparkFun-Resistors    (3.03275591 3.03401575) R180
R96      1K              0603-RES      SparkFun-Resistors    (3.70275591 3.04401575) R270
U1       MCP73831        SOT23-5       SparkFun              (1.54425197 0.14031496) R180
U2       MCP73831        SOT23-5       SparkFun              (0.56 0.14031496)     R180
U3       MCP73831        SOT23-5       SparkFun              (0.56 1.10488189)     R180
U4       MCP73831        SOT23-5       SparkFun              (1.54425197 1.10488189) R180
U5       MCP73831        SOT23-5       SparkFun              (2.52850394 0.14031496) R180
U6       MCP73831        SOT23-5       SparkFun              (3.51275591 0.14031496) R180
U7       MCP73831        SOT23-5       SparkFun              (2.52850394 1.10488189) R180
U8       MCP73831        SOT23-5       SparkFun              (3.51275591 1.10488189) R180
U9       MCP73831        SOT23-5       SparkFun              (0.56 2.06944882)     R180
U10      MCP73831        SOT23-5       SparkFun              (1.54425197 2.06944882) R180
U11      MCP73831        SOT23-5       SparkFun              (0.56 3.03401575)     R180
U12      MCP73831        SOT23-5       SparkFun              (1.54425197 3.03401575) R180
U13      MCP73831        SOT23-5       SparkFun              (2.52850394 2.06944882) R180
U14      MCP73831        SOT23-5       SparkFun              (3.51275591 2.06944882) R180
U15      MCP73831        SOT23-5       SparkFun              (2.52850394 3.03401575) R180
U16      MCP73831        SOT23-5       SparkFun              (3.51275591 3.03401575) R180

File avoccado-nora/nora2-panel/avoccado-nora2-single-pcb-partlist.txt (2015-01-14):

Partlist

Exported from avoccado-avr-pcb-nora-2.brd 

EAGLE Version 7.2.0 Copyright (c) 1988-2014 CadSoft

Assembly variant: 

Part     Value           Package       Library               Position (inch)       Orientation

AVR      ATMEGA328P      TQFP32-08     SparkFun-DigitalIC    (0.58 0.62031496)     R180
C1       0.1uF           C0402         SparkFun              (0.35 0.64031496)     R90
C2       0.1uF           C0402         SparkFun              (0.78 0.26031496)     R0
C3       0.1uF           C0402         SparkFun              (0.82 0.60031496)     R90
C4       4.7uF           0603-CAP      SparkFun-Capacitors   (0.45 0.15031496)     R90
C5       4.7uF           0603-CAP      SparkFun-Capacitors   (0.23 0.15031496)     R90
C6       4.7uF           0603-CAP      SparkFun-Capacitors   (0.42 0.26031496)     R0
C10      0.1uF           C0402         SparkFun              (0.28 0.26031496)     R180
D1       LED             LED-0603      SparkFun              (0.80 0.04) 	       R270
LDO      MCP1703CB       SOT23         linear                (0.35 0.15031496)     R180
Q1       16MHz           RESONATOR-SMD SparkFun              (0.82 0.83231496)     R0
Q2       FET             SOT323        SparkFun-DiscreteSemi (0.08 0.06031496)     R270
R1       1K              0603-RES      SparkFun-Resistors    (0.08 0.20031496)     R180
R2       10K             0603-RES      SparkFun-Resistors    (0.08 0.26031496)     R180
R3       2K              0603-RES      SparkFun-Resistors    (0.67 0.15031496)     R270
R4       1K              0603-RES      SparkFun-Resistors    (0.83 0.15031496)     R90
R5       1M              0603-RES      SparkFun-Resistors    (0.08 0.14031496)     R180
R6       1K              0603-RES      SparkFun-Resistors    (0.75 0.15031496)     R270
U2       MCP73831        SOT23-5       SparkFun              (0.56 0.14031496)     R180

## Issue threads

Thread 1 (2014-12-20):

pin 1 and 2 (Vcc and GND) swapped at MPU6050 header

aShure, 2014-12-20:

aShure, 2015-05-14:
fixed with second PCB

Closed 2015-05-14.

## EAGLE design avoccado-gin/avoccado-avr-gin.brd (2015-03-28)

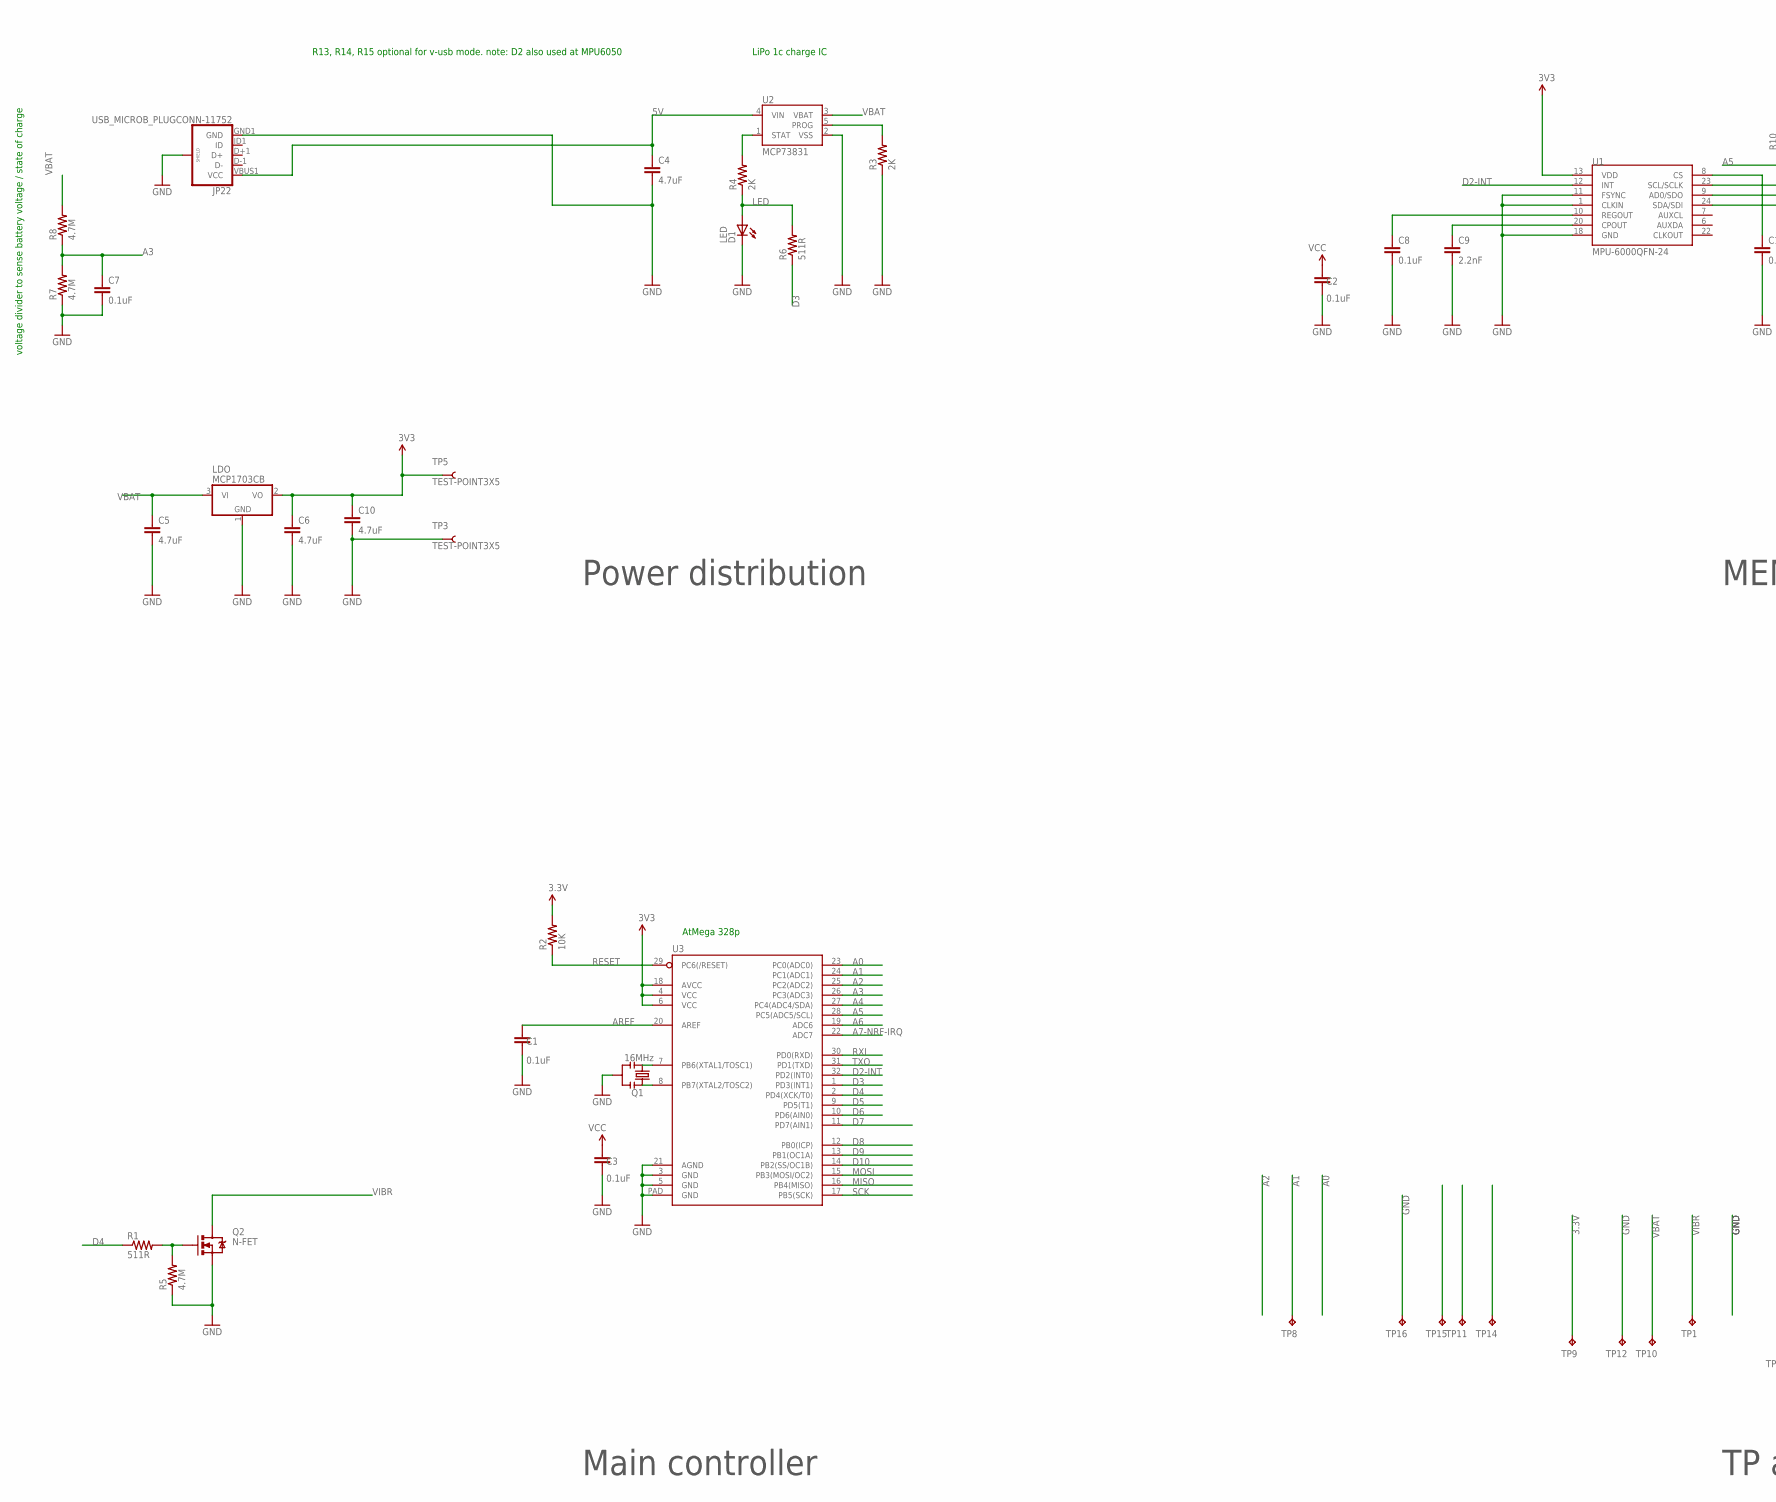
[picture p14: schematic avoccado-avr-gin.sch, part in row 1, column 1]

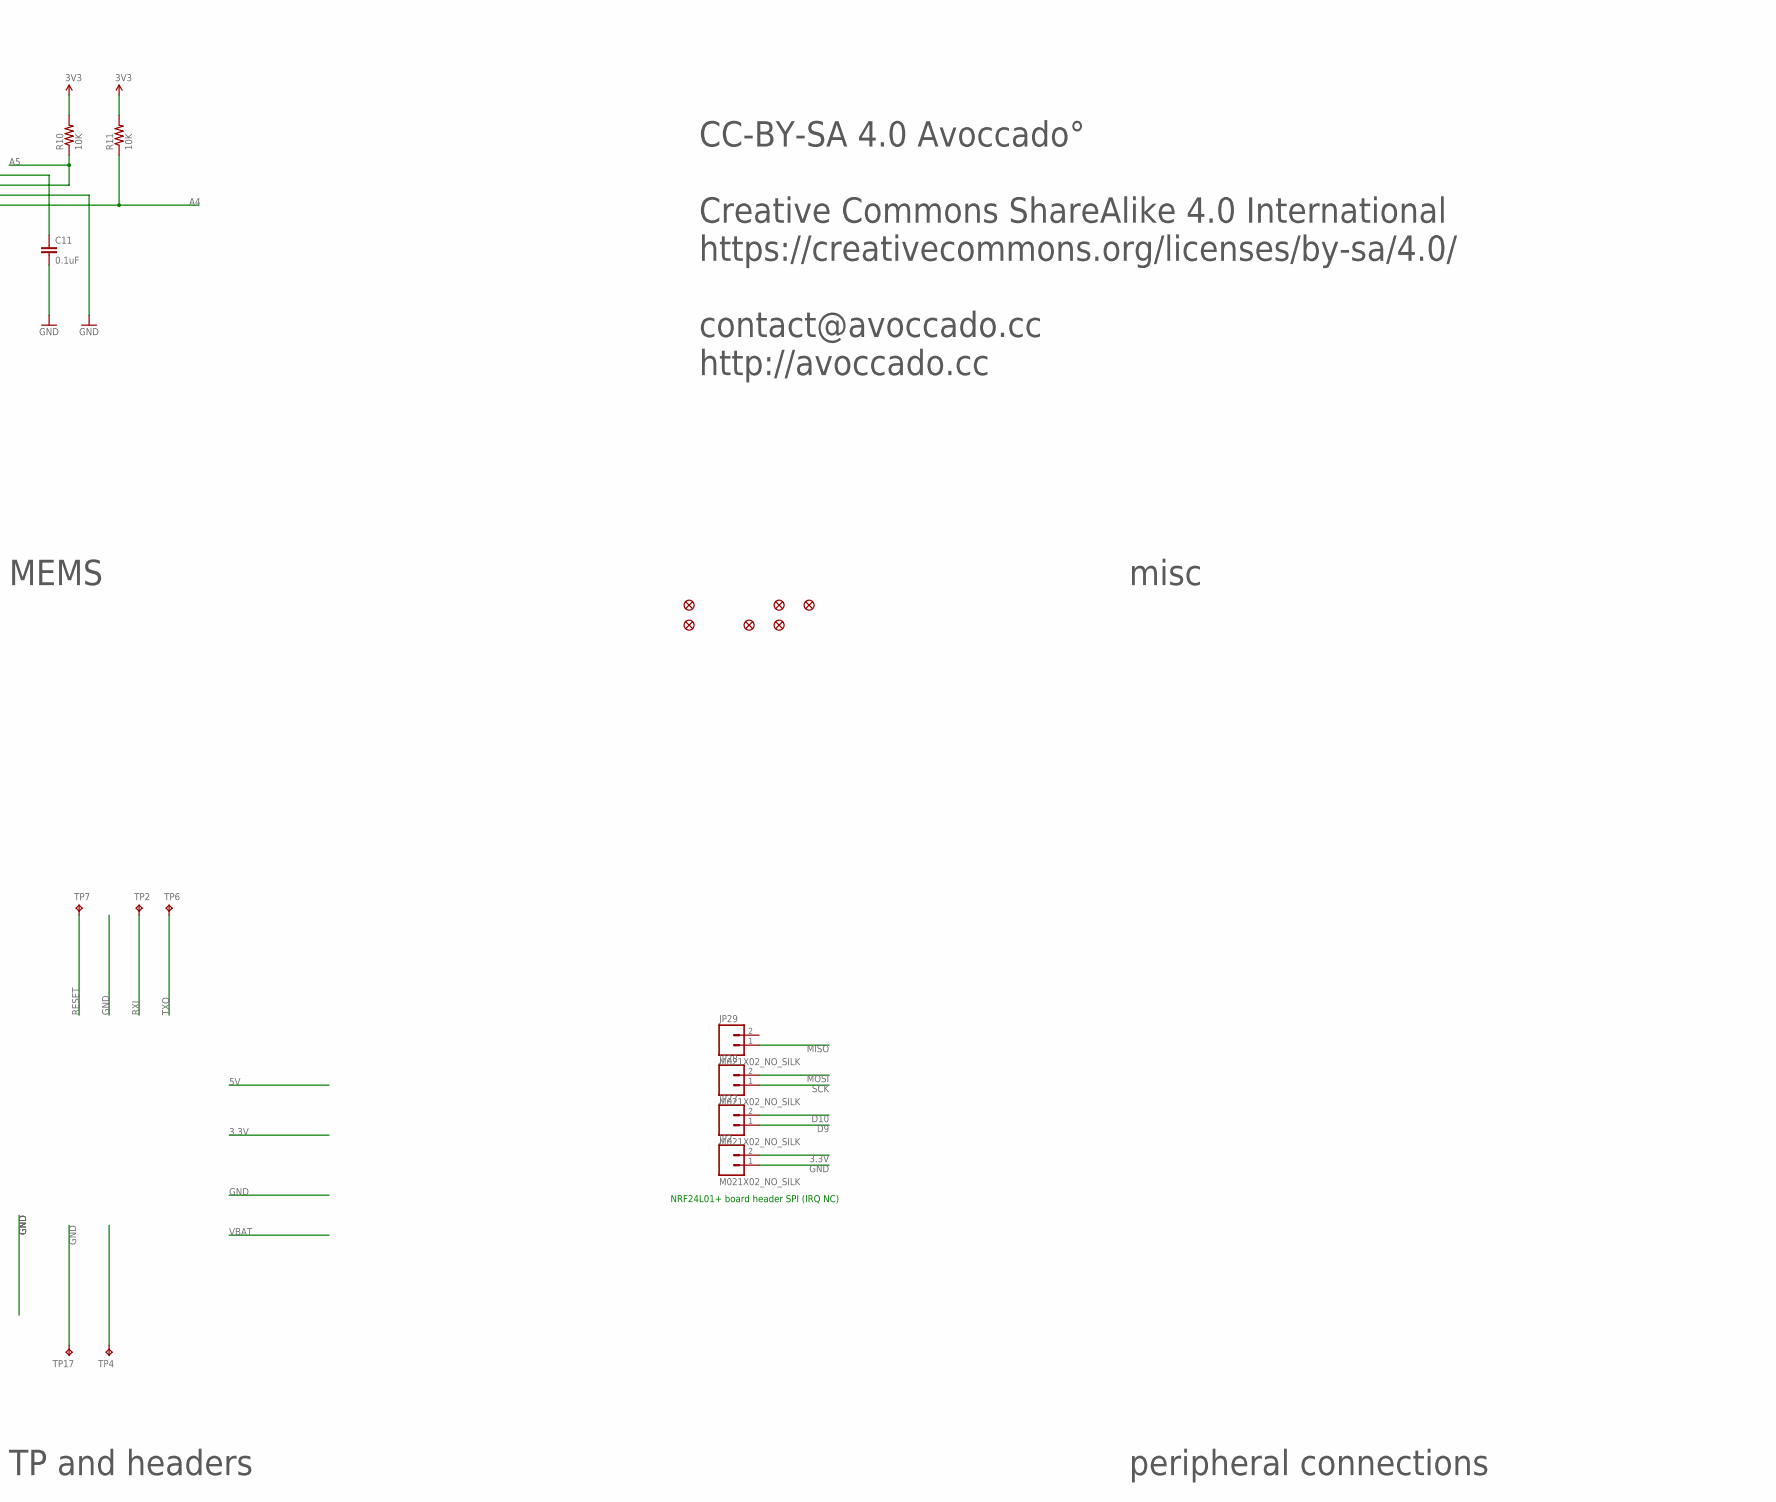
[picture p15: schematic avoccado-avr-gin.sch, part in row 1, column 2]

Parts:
C1, C2, C3, C7, C8, C11: 0.1uF; C0402K
C4, C5, C6: 4.7uF; 0603-CAP
C9: 2.2nF; C0402K
C10: 4.7uF; C0603
D1: LED; LED-0603
FID2, FID4, FID5, FID6, FID8, FID9: FIDUCIALUFIDUCIAL; MICRO-FIDUCIAL
JP2, JP27, JP28, JP29: M021X02_NO_SILK; 1X02_NO_SILK
JP22: USB_MICROB_PLUGCONN-11752; USB-B-MICRO-SMD_V03
LDO: MCP1703CB; SOT23
Q1: 16MHz; RESONATOR-SMD
Q2: N-FET; SOT23-3
R1, R6: 511R; 0603-RES
R2, R10, R11: 10K; 0603-RES
R3, R4: 2K; 0603-RES
R5, R7, R8: 4.7M; 0603-RES
TP1, TP2, TP4, TP6, TP7, TP8, TP9, TP10, TP11, TP12, TP14, TP15, TP16, TP17: TPTP20R; TP20R
TP3, TP5: TEST-POINT3X5; PAD.03X.05
U1: MPU-6000QFN-24; QFN-24-TESTING
U2: MCP73831; SOT23-5
U3: ATMEGA328P_MLFMLF32; MLF32-PAD

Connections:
3.3V: C2.2, C3.2, C6.1, C10.1, JP2.2, LDO.2 (VO), R2.2, R10.2, R11.2, TP5.P$1, TP9.TP, U1.13 (VDD), U3.4 (VCC), U3.6 (VCC), U3.18 (AVCC)
5V: C4.1, JP22.VBUS1 (VCC), U2.4 (VIN)
A0: U3.23 (PC0(ADC0))
A1: TP8.TP, U3.24 (PC1(ADC1))
A2: U3.25 (PC2(ADC2))
A3: C7.1, R7.2, R8.1, U3.26 (PC3(ADC3))
A4: R11.1, U1.24 (SDA/SDI), U3.27 (PC4(ADC4/SDA))
A5: R10.1, U1.23 (SCL/SCLK), U3.28 (PC5(ADC5/SCL))
A6: U3.19 (ADC6)
A7-NRF-IRQ: U3.22 (ADC7)
AREF: C1.2, U3.20 (AREF)
CHG-PROG: R3.2, U2.5 (PROG)
D2-INT: U1.12 (INT), U3.32 (PD2(INT0))
D3: R6.1, U3.1 (PD3(INT1))
D4: R1.1, U3.2 (PD4(XCK/T0))
D5: TP15.TP, U3.9 (PD5(T1))
D6: U3.10 (PD6(AIN0))
D7: TP14.TP, U3.11 (PD7(AIN1))
D8: TP11.TP, U3.12 (PB0(ICP))
D9: JP27.1, U3.13 (PB1(OC1A))
D10: JP27.2, U3.14 (PB2(SS/OC1B))
GND: C1.1, C2.1, C3.1, C4.2, C5.2, C6.2, C7.2, C8.2, C9.2, C10.2, C11.2, D1.C, JP2.1, JP22.GND1 (GND), JP22.SHIELD1 (SHIELD), JP22.SHIELD2 (SHIELD), JP22.SHIELD3 (SHIELD), LDO.1 (GND), Q1.2, Q2.2 (S), R3.1, R5.1, R7.1, TP3.P$1, TP12.TP, TP16.TP, TP17.TP, U1.1 (CLKIN), U1.9 (AD0/SDO), U1.11 (FSYNC), U1.18 (GND), U2.2 (VSS), U3.3 (GND), U3.5 (GND), U3.21 (AGND), U3.PAD (GND)
LED: D1.A, R4.1, R6.2
MISO: JP29.1, U3.16 (PB4(MISO))
MOSI: JP28.2, U3.15 (PB3(MOSI/OC2))
unnamed: Q1.1, U3.8 (PB7(XTAL2/TOSC2))
unnamed: Q1.3, U3.7 (PB6(XTAL1/TOSC1))
unnamed: Q2.1 (G), R1.2, R5.2
unnamed: C8.1, U1.10 (REGOUT)
unnamed: C9.1, U1.20 (CPOUT)
unnamed: C11.1, U1.8 (CS)
RESET: R2.1, TP7.TP, U3.29 (PC6(/RESET))
RXI: TP2.TP, U3.30 (PD0(RXD))
SCK: JP28.1, U3.17 (PB5(SCK))
SOC: R4.2, U2.1 (STAT)
TXO: TP6.TP, U3.31 (PD1(TXD))
VBAT: C5.1, LDO.3 (VI), R8.2, TP4.TP, TP10.TP, U2.3 (VBAT)
VIBR: Q2.3 (D), TP1.TP

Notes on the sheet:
NRF24L01+ board header SPI (IRQ NC)
AtMega 328p
LiPo 1c charge IC
voltage divider to sense battery voltage / state of charge
R13, R14, R15 optional for v-usb mode. note: D2 also used at MPU6050
Power distribution
Main controller
TP and headers
peripheral connections
misc
MEMS
CC-BY-SA 4.0 Avoccado° Creative Commons ShareAlike 4.0 International https://creativecommons.org/licenses/by-sa/4.0/ contact@avoccado.cc http://avoccado.cc

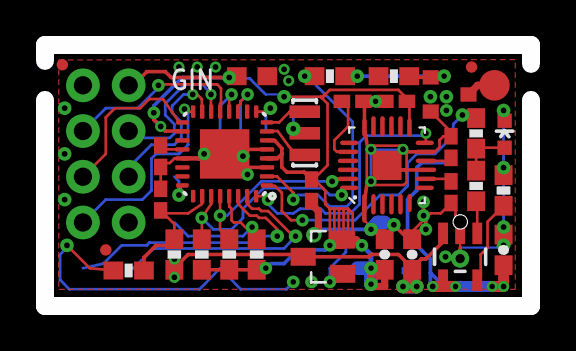
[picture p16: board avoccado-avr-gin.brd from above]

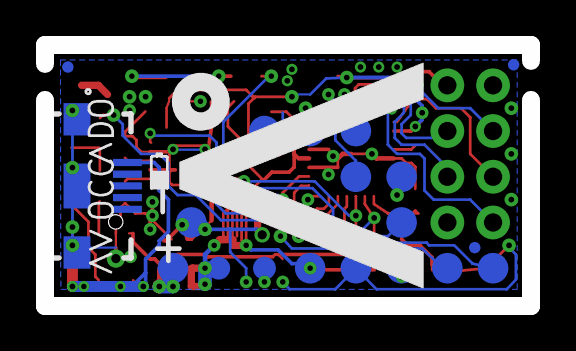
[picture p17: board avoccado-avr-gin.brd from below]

Board: 2 copper layers, 27.0 x 14.5 mm, 55 parts (19 on the bottom side), 33 nets.

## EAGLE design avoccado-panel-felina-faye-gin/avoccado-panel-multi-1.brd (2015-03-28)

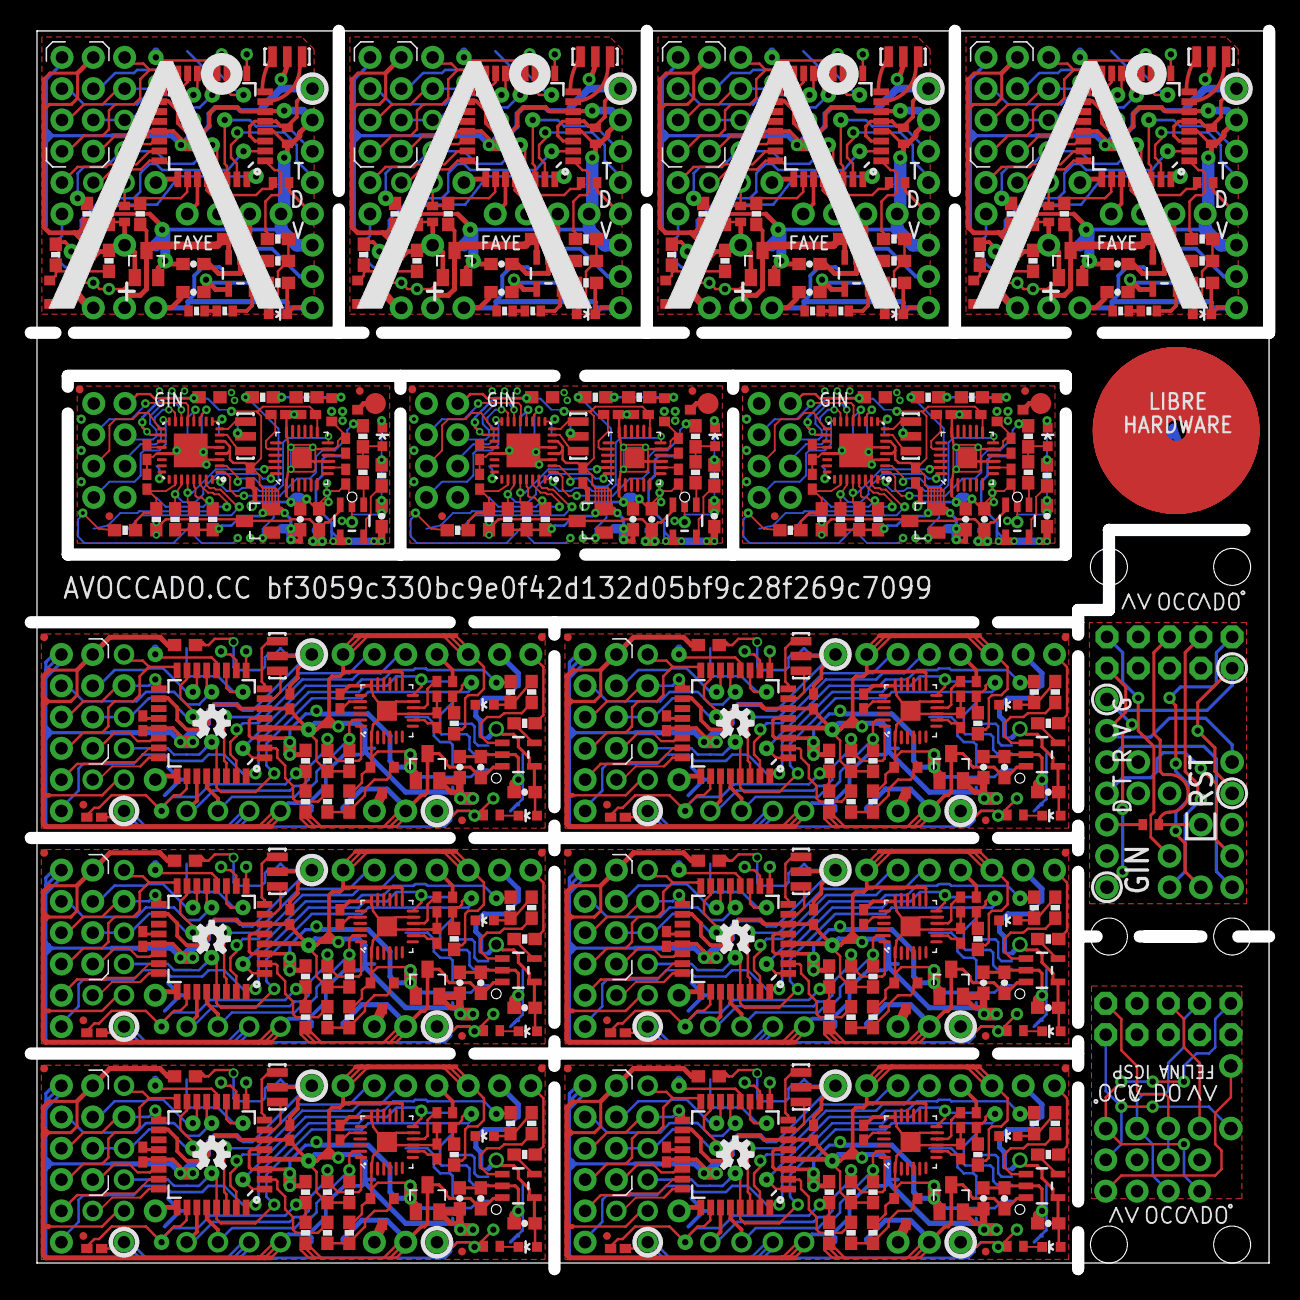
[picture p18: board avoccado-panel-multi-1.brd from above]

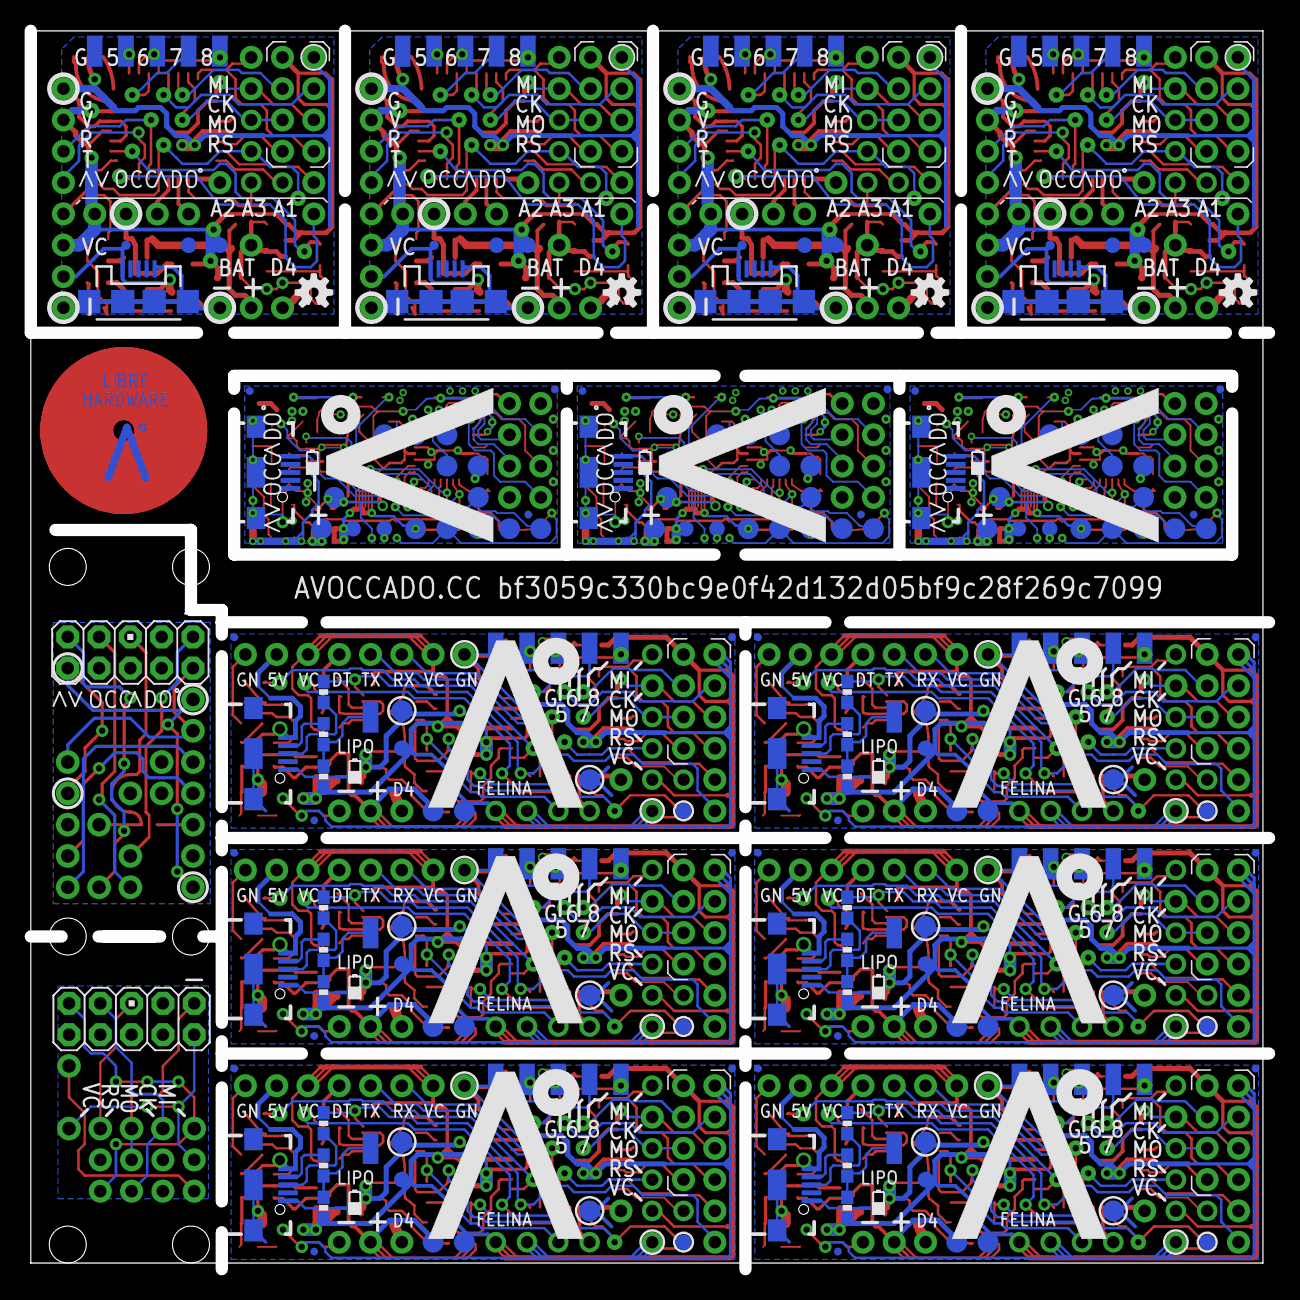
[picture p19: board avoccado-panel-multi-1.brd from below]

Board: 2 copper layers, 100.0 x 100.0 mm, 939 parts (213 on the bottom side), 510 nets.

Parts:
C1, C2, C3, C7, C8, C11, C13, C14, C16, C19, C20, C22, C24, C25, C27, C30, C31, C33, C35, C36, C38, C41, C42, C44, C46, C47, C49, C52, C53, C55, C57, C58, C60, C63, C64, C66, C68, C69, C73, C74, C76, C77, C79, C80, C84, C85, C87, C88, C98, C99, C127, C128, C130, C131: 0.1uF; C0402K
C4, C5, C6, C15, C17, C18, C26, C28, C29, C37, C39, C40, C48, C50, C51, C59, C61, C62, C70, C71, C72, C81, C82, C83, C92, C94, C95, C103, C105, C106, C111, C113, C114, C119, C121, C122, C124, C125, C126: 4.7uF; 0603-CAP
C9, C21, C32, C43, C54, C65, C75, C86, C129: 2.2nF; C0402K
C10, C12, C23, C34, C45, C56: 0.1uF; C0603
C67, C78, C97: 4.7uF; C0603
C89, C90, C91, C93, C96, C100, C101, C102, C104, C107, C108, C109, C110, C112, C115, C116, C117, C118, C120, C123: 0.1uF; C0402
C132: C0402
D1, D2, D3, D4, D5, D6, D7, D8, D9, D10, D11, D12, D13, D14, D15, D16, D17, D18, D19: LED; LED-0603
FID1, FID2, FID3, FID4, FID5, FID6, FID7, FID8, FID9, FID10, FID11, FID12, FID13, FID14, FID15, FID16, FID17, FID18, FID19, FID20, FID21, FID22, FID23, FID24, FID25, FID26, FID27, FID28, FID29, FID30, FID31, FID32, FID33, FID34, FID35, FID36, FID37, FID38, FID39, FID40, FID41, FID42, FID43, FID44, FID45, FID46, FID47, FID48, FID49, FID50, FID51, FID52, FID53, FID54, FID55, FID56, FID57, FID58, FID59, FID60: FIDUCIALUFIDUCIAL; MICRO-FIDUCIAL
JP1, JP4, JP5, JP12, JP14, JP15, JP16, JP20, JP30, JP31, JP35, JP37, JP38, JP43, JP52, JP53, JP54, JP55, JP56, JP57, JP64, JP66, JP67, JP72, JP81, JP82, JP83, JP84, JP85, JP86, JP93, JP95, JP96, JP101, JP110, JP111, JP112, JP113, JP114, JP115, JP122, JP124, JP125, JP130, JP139, JP140, JP141, JP142, JP143, JP144, JP151, JP153, JP154, JP159, JP168, JP169, JP170, JP171, JP172, JP173, JP197, JP198, JP203, JP205, JP224, JP225, JP230, JP232, JP251, JP252, JP257, JP259, JP273, JP274, JP279, JP281: M01NOSILK-KIT; 1X01NS-KIT
JP2, JP27, JP28, JP29, JP48, JP49, JP50, JP51, JP77, JP78, JP79, JP80, JP106, JP107, JP108, JP109, JP135, JP136, JP137, JP138, JP164, JP165, JP166, JP167, JP175, JP176, JP177, JP178, JP180, JP181, JP182, JP183, JP210, JP211, JP212, JP213, JP214, JP215, JP237, JP238, JP239, JP240, JP241, JP242, JP264, JP265, JP266, JP267, JP268, JP269, JP286, JP287, JP288, JP289, JP290, JP291, JP293, JP294, JP295, JP296, JP876, JP877, JP878, JP879: M021X02_NO_SILK; 1X02_NO_SILK
JP3, JP6, JP7, JP8, JP9, JP10, JP11, JP13, JP17, JP18, JP19, JP21, JP23, JP24, JP25, JP26, JP32, JP33, JP34, JP36, JP39, JP40, JP41, JP42, JP44, JP45, JP46, JP47, JP59, JP60, JP61, JP62, JP63, JP65, JP68, JP69, JP70, JP71, JP73, JP74, JP75, JP76, JP88, JP89, JP90, JP91, JP92, JP94, JP97, JP98, JP99, JP100, JP102, JP103, JP104, JP105, JP117, JP118, JP119, JP120, JP121, JP123, JP126, JP127, JP128, JP129, JP131, JP132, JP133, JP134, JP146, JP147, JP148, JP149, JP150, JP152, JP155, JP156, JP157, JP158, JP160, JP161, JP162, JP163, JP185, JP186, JP187, JP188, JP189, JP190, JP191, JP192, JP193, JP194, JP195, JP196, JP199, JP200, JP201, JP202, JP204, JP206, JP207, JP208, JP209, JP217, JP218, JP219, JP220, JP221, JP222, JP223, JP226, JP227, JP228, JP229, JP231, JP233, JP234, JP235, JP236, JP244, JP245, JP246, JP247, JP248, JP249, JP250, JP253, JP254, JP255, JP256, JP258, JP260, JP261, JP262, JP263, JP271, JP272, JP275, JP276, JP277, JP278, JP280, JP282, JP283, JP284, JP285: M01PTH; 1X01
JP22, JP58, JP87, JP116, JP145, JP174, JP179, JP184, JP297: USB_MICROB_PLUGCONN-11752; USB-B-MICRO-SMD_V03
JP216, JP243, JP270, JP292: USB-MICROB
LDO, LDO1, LDO2, LDO3, LDO4, LDO5, LDO6, LDO7, LDO8, LDO9, LDO10, LDO11, LDO12: MCP1703CB; SOT23
LOGO1, LOGO2, LOGO3, LOGO4, LOGO5, LOGO6, LOGO7, LOGO8, LOGO9, LOGO10: OSHW-LOGOS; OSHW-LOGO-S
MCU, MCU1, MCU2, MCU3, MCU4, MCU5, MCU6, MCU7, MCU8, MCU9: ATMEGA328P_TQFP; TQFP32-08
Q1, Q3, Q5, Q7, Q9, Q11, Q13, Q15, Q17, Q19, Q21, Q23, Q25: 16MHz; RESONATOR-SMD
Q2, Q4, Q6, Q8, Q10, Q12, Q18, Q20, Q22, Q24: FET; SOT23-3
Q14, Q16, Q26: N-FET; SOT23-3
R1, R6, R16, R20, R30, R34, R44, R48, R58, R62, R72, R76, R86, R90, R96, R100, R106, R110, R116, R120, R126, R130, R136, R140, R146, R150: 511R; 0603-RES
R2, R10, R11, R12, R23, R24, R29, R37, R38, R43, R51, R52, R57, R65, R66, R71, R79, R80, R85, R93, R94, R95, R103, R104, R105, R115, R125, R135, R145, R153, R154: 10K; 0603-RES
R3, R4, R15, R17, R18, R27, R31, R32, R41, R45, R46, R55, R59, R60, R69, R73, R74, R83, R87, R88, R97, R98, R147, R148: 2K; 0603-RES
R5, R7, R8, R19, R21, R22, R33, R35, R36, R47, R49, R50, R61, R63, R64, R75, R77, R78, R89, R91, R92, R99, R101, R102, R109, R111, R112, R119, R121, R122, R129, R131, R132, R139, R141, R142, R149, R151, R152: 4.7M; 0603-RES
R9, R28, R42, R56, R70, R84: 2K; R0402
R13, R14, R25, R26, R39, R40, R53, R54, R67, R68, R81, R82: 68R; 0603-RES
R107, R117, R127, R137: RP; 0603-RES
R108, R118, R128, R138: 1K; 0603-RES
R113, R114, R123, R124, R133, R134, R143, R144: 1K; 0402-RES
TP1, TP6, TP7, TP8, TP9, TP11, TP14, TP15, TP16, TP17, TP21, TP23, TP27, TP28, TP29, TP30, TP34, TP36, TP40, TP41, TP42, TP43, TP47, TP49, TP53, TP54, TP55, TP56, TP60, TP62, TP66, TP67, TP68, TP69, TP73, TP75, TP111, TP112, TP113, TP114, TP119, TP127, TP128, TP129, TP130, TP135, TP136, TP137, TP138, TP139, TP144, TP145, TP146, TP147, TP148, TP153: TEST-POINT2; PAD.02X.02
TP2, TP18, TP31, TP44, TP57, TP70, TP115, TP131, TP140, TP149: M01PTH; 1X01
TP3, TP5, TP19, TP20, TP32, TP33, TP45, TP46, TP58, TP59, TP71, TP72, TP79, TP80, TP95, TP96, TP116, TP117, TP120, TP121, TP132, TP133, TP141, TP142, TP150, TP151: TEST-POINT3X5; PAD.03X.05
TP4, TP10, TP12, TP13, TP22, TP24, TP25, TP26, TP35, TP37, TP38, TP39, TP48, TP50, TP51, TP52, TP61, TP63, TP64, TP65, TP74, TP76, TP77, TP78, TP81, TP82, TP83, TP84, TP85, TP86, TP87, TP88, TP89, TP90, TP91, TP92, TP93, TP94, TP97, TP98, TP99, TP100, TP101, TP102, TP103, TP104, TP105, TP106, TP107, TP108, TP109, TP110, TP122, TP123, TP124, TP125, TP126, TP154, TP155, TP156, TP157, TP158, TP159, TP160, TP161, TP162: TPTP20R; TP20R
TP118, TP134, TP143, TP152: TEST-POINT3; PAD.03X.03
TP163, TP164, TP165, TP166, TP167, TP168, TP169, TP170, TP171, TP172, TP173, TP174, TP175, TP176, TP177, TP178, TP179, TP180, TP181, TP559, TP560, TP561, TP562, TP563, TP564: PTR1PAD1-13; P1-13
U1, U4, U6, U8, U10, U12, U14, U17, U21: MPU-6000QFN-24; QFN-24-TESTING
U2, U3, U5, U7, U9, U11, U13, U16, U19, U20, U22, U23, U24: MCP73831; SOT23-5
U15, U18, U25: MLF32-PAD
U$1, U$6: AVR_SPI_PROG; AVR_ICSP

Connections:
3.3V: C3.2, C6.1, C10.1, JP1.1, JP2.2, JP4.1, JP11.1, JP18.1, LDO.2, MCU.4, MCU.6, MCU.18, R2.2, R10.2, R11.2, R15.2, TP5.P$1, TP13.TP, U1.13
3.3V1: C12.1, C13.2, C18.1, JP34.1, JP41.1, JP48.2, JP52.1, JP56.1, LDO1.2, MCU1.4, MCU1.6, MCU1.18, R12.2, R23.2, R24.2, R27.2, TP19.P$1, TP25.TP, U4.13
3.3V2: C23.1, C24.2, C29.1, JP63.1, JP70.1, JP77.2, JP81.1, JP85.1, LDO2.2, MCU2.4, MCU2.6, MCU2.18, R29.2, R37.2, R38.2, R41.2, TP32.P$1, TP38.TP, U6.13
3.3V3: C34.1, C35.2, C40.1, JP92.1, JP99.1, JP106.2, JP110.1, JP114.1, LDO3.2, MCU3.4, MCU3.6, MCU3.18, R43.2, R51.2, R52.2, R55.2, TP45.P$1, TP51.TP, U8.13
3.3V4: C45.1, C46.2, C51.1, JP121.1, JP128.1, JP135.2, JP139.1, JP143.1, LDO4.2, MCU4.4, MCU4.6, MCU4.18, R57.2, R65.2, R66.2, R69.2, TP58.P$1, TP64.TP, U10.13
3.3V5: C56.1, C57.2, C62.1, JP150.1, JP157.1, JP164.2, JP168.1, JP172.1, LDO5.2, MCU5.4, MCU5.6, MCU5.18, R71.2, R79.2, R80.2, R83.2, TP71.P$1, TP77.TP, U12.13
3.3V6: C67.1, C68.2, C72.1, C77.2, JP175.2, LDO6.2, R85.2, R93.2, R94.2, TP79.P$1, TP89.TP, U14.13, U15.4, U15.6, U15.18
3.3V7: C78.1, C79.2, C83.1, C88.2, JP180.2, LDO7.2, R95.2, R103.2, R104.2, TP95.P$1, TP105.TP, U17.13, U18.4, U18.6, U18.18
3.3V8: C89.1, C90.2, C95.1, JP189.1, JP277.1, JP286.2, JP290.1, LDO8.2, MCU9.4, MCU9.6, MCU9.18, R105.2, TP116.P$1
3.3V9: C100.1, C101.2, C106.1, JP194.1, JP201.1, JP210.2, JP214.1, LDO9.2, MCU6.4, MCU6.6, MCU6.18, R115.2, TP132.P$1
3.3V10: C108.1, C109.2, C114.1, JP221.1, JP228.1, JP237.2, JP241.1, LDO10.2, MCU7.4, MCU7.6, MCU7.18, R125.2, TP141.P$1
3.3V11: C116.1, C117.2, C122.1, JP248.1, JP255.1, JP264.2, JP268.1, LDO11.2, MCU8.4, MCU8.6, MCU8.18, R135.2, TP150.P$1
3.3V12: C97.1, C98.2, C126.1, C131.2, JP293.2, LDO12.2, R145.2, R153.2, R154.2, TP120.P$1, TP157.TP, U21.13, U25.4, U25.6, U25.18
3.3V13: TP169.TP, TP175.TP, TP180.TP, U$1.2
3.3V44: JP876.2, TP560.TP, U$6.2
5V: C4.1, D2.A, JP17.1, JP22.VBUS1, U2.4
5V1: C15.1, D4.A, JP40.1, JP58.VBUS1, U3.4
5V2: C26.1, D6.A, JP69.1, JP87.VBUS1, U5.4
5V3: C37.1, D8.A, JP98.1, JP116.VBUS1, U7.4
5V4: C48.1, D10.A, JP127.1, JP145.VBUS1, U9.4
5V5: C59.1, D12.A, JP156.1, JP174.VBUS1, U11.4
5V6: C70.1, JP179.VBUS1, U13.4
5V7: C81.1, JP184.VBUS1, U16.4
5V8: C92.1, JP276.1, JP292.VBUS, TP118.P$1, U19.4
5V9: C103.1, JP200.1, JP216.VBUS, TP134.P$1, U22.4
5V10: C111.1, JP227.1, JP243.VBUS, TP143.P$1, U23.4
5V11: C119.1, JP254.1, JP270.VBUS, TP152.P$1, U24.4
5V12: C124.1, JP297.VBUS1, U20.4
7-TO-D-: R14.1, R15.1, TP11.P$1
7-TO-D-1: R26.1, R27.1, TP23.P$1
7-TO-D-2: R40.1, R41.1, TP36.P$1
7-TO-D-3: R54.1, R55.1, TP49.P$1
7-TO-D-4: R68.1, R69.1, TP62.P$1
7-TO-D-5: R82.1, R83.1, TP75.P$1
A0: JP19.1, MCU.23
A1: JP20.1, MCU.24
A2: JP21.1, MCU.25
A3: C7.1, MCU.26, R7.2, R8.1
A4: JP31.1, MCU.27, R11.1, U1.24
A5: JP30.1, MCU.28, R10.1, U1.23
A7: JP54.1, MCU1.28, R23.1, U4.23
A7-NRF-IRQ: JP29.2, MCU.22
A7-NRF-IRQ1: JP51.2, MCU1.22
A7-NRF-IRQ2: JP80.2, MCU2.22
A7-NRF-IRQ3: JP109.2, MCU3.22
A7-NRF-IRQ4: JP138.2, MCU4.22
A7-NRF-IRQ5: JP167.2, MCU5.22
A7-NRF-IRQ8: JP289.2, MCU9.22
A7-NRF-IRQ9: JP213.2, MCU6.22
A7-NRF-IRQ10: JP240.2, MCU7.22
A7-NRF-IRQ11: JP267.2, MCU8.22
A8: JP55.1, MCU1.27, R24.1, U4.24
A9: C19.1, MCU1.26, R21.2, R22.1
A10: JP44.1, MCU1.25
A11: JP43.1, MCU1.24
A12: JP42.1, MCU1.23
A14: JP83.1, MCU2.28, R37.1, U6.23
A15: JP84.1, MCU2.27, R38.1, U6.24
A16: C30.1, MCU2.26, R35.2, R36.1
A17: JP73.1, MCU2.25
A18: JP72.1, MCU2.24
A19: JP71.1, MCU2.23
A21: JP112.1, MCU3.28, R51.1, U8.23
A22: JP113.1, MCU3.27, R52.1, U8.24
A23: C41.1, MCU3.26, R49.2, R50.1
A24: JP102.1, MCU3.25
A25: JP101.1, MCU3.24
A26: JP100.1, MCU3.23
A28: JP141.1, MCU4.28, R65.1, U10.23
A29: JP142.1, MCU4.27, R66.1, U10.24
A30: C52.1, MCU4.26, R63.2, R64.1
A31: JP131.1, MCU4.25
A32: JP130.1, MCU4.24
A33: JP129.1, MCU4.23
A35: JP170.1, MCU5.28, R79.1, U12.23
A36: JP171.1, MCU5.27, R80.1, U12.24
A37: C63.1, MCU5.26, R77.2, R78.1
A38: JP160.1, MCU5.25
A39: JP159.1, MCU5.24
A40: JP158.1, MCU5.23
A42: R93.1, U14.23, U15.28
A43: R94.1, U14.24, U15.27
A44: C73.1, R91.2, R92.1, U15.26
A46: TP88.TP, U15.24
A49: R103.1, U17.23, U18.28
A50: R104.1, U17.24, U18.27
A51: C84.1, R101.2, R102.1, U18.26
A53: TP104.TP, U18.24
A56: JP291.1, MCU9.28
A57: JP291.2, MCU9.27
A58: C96.1, JP281.1, MCU9.26, R111.2, R112.1
A59: JP280.1, MCU9.25
A60: JP279.1, MCU9.24
A61: JP278.1, MCU9.23
A63: JP215.1, MCU6.28
A64: JP215.2, MCU6.27
A65: C107.1, JP205.1, MCU6.26, R121.2, R122.1
A66: JP204.1, MCU6.25
A67: JP203.1, MCU6.24
A68: JP202.1, MCU6.23
A70: JP242.1, MCU7.28
A71: JP242.2, MCU7.27
A72: C115.1, JP232.1, MCU7.26, R131.2, R132.1
A73: JP231.1, MCU7.25
A74: JP230.1, MCU7.24
A75: JP229.1, MCU7.23
A77: JP269.1, MCU8.28
A78: JP269.2, MCU8.27
A79: C123.1, JP259.1, MCU8.26, R141.2, R142.1
A80: JP258.1, MCU8.25
A81: JP257.1, MCU8.24
A82: JP256.1, MCU8.23
A84: R153.1, U21.23, U25.28
A85: R154.1, U21.24, U25.27
A86: C127.1, R151.2, R152.1, U25.26
A88: TP156.TP, U25.24
AREF: C1.2, MCU.20
AREF1: C14.2, MCU1.20
AREF2: C25.2, MCU2.20
AREF3: C36.2, MCU3.20
AREF4: C47.2, MCU4.20
AREF5: C58.2, MCU5.20
AREF6: C69.2, U15.20
AREF7: C80.2, U18.20
AREF8: C91.2, MCU9.20
AREF9: C102.2, MCU6.20
AREF10: C110.2, MCU7.20
AREF11: C118.2, MCU8.20
AREF12: C99.2, U25.20
CHG-PROG: R3.2, U2.5
CHG-PROG1: R17.2, U3.5
CHG-PROG2: R31.2, U5.5
CHG-PROG3: R45.2, U7.5
CHG-PROG4: R59.2, U9.5
CHG-PROG5: R73.2, U11.5
CHG-PROG6: R87.2, U13.5
CHG-PROG7: R97.2, U16.5
CHG-PROG8: R107.2, R113.2, U19.5
CHG-PROG9: R117.2, R123.2, U22.5
CHG-PROG10: R127.2, R133.2, U23.5
CHG-PROG11: R137.2, R143.2, U24.5
CHG-PROG12: R147.2, U20.5
D1: JP49.1, MCU1.13
D2: MCU1.12, TP17.P$1
D2-INT: MCU.32, R13.1, TP2.1, U1.12
D2-INT1: MCU1.32, R25.1, TP18.1, U4.12
D2-INT2: MCU2.32, R39.1, TP31.1, U6.12
D2-INT3: MCU3.32, R53.1, TP44.1, U8.12
D2-INT4: MCU4.32, R67.1, TP57.1, U10.12
D2-INT5: MCU5.32, R81.1, TP70.1, U12.12
D2-INT6: U14.12, U15.32
D2-INT7: U17.12, U18.32
D2-INT8: U21.12, U25.32
D3: MCU.1, R6.1
D4: MCU.2, R1.1
D5: MCU.9, TP1.P$1
D6: MCU.10, TP6.P$1
D7: MCU.11, TP7.P$1
D8: MCU.12, TP8.P$1
D9: JP27.1, MCU.13
D10: JP27.2, MCU.14
D11: MCU1.1, R20.1
D12: MCU1.2, R16.1
D13: MCU1.9, TP14.P$1
D14: MCU1.10, TP15.P$1
D15: MCU1.11, TP16.P$1
D16: JP49.2, MCU1.14
D17: JP78.1, MCU2.13
D18: MCU2.12, TP30.P$1
D19: MCU2.1, R34.1
D20: MCU2.2, R30.1
D21: MCU2.9, TP27.P$1
D22: MCU2.10, TP28.P$1
D23: MCU2.11, TP29.P$1
D24: JP78.2, MCU2.14
D25: JP107.1, MCU3.13
D26: MCU3.12, TP43.P$1
D27: MCU3.1, R48.1
D28: MCU3.2, R44.1
D29: MCU3.9, TP40.P$1
D30: MCU3.10, TP41.P$1
D31: MCU3.11, TP42.P$1
D32: JP107.2, MCU3.14
D33: JP136.1, MCU4.13
D34: MCU4.12, TP56.P$1
D35: MCU4.1, R62.1
D36: MCU4.2, R58.1
D37: MCU4.9, TP53.P$1
D38: MCU4.10, TP54.P$1
D39: MCU4.11, TP55.P$1
D40: JP136.2, MCU4.14
D41: JP165.1, MCU5.13
D42: MCU5.12, TP69.P$1
D43: MCU5.1, R76.1
D44: MCU5.2, R72.1
D45: MCU5.9, TP66.P$1
D46: MCU5.10, TP67.P$1
D47: MCU5.11, TP68.P$1
D48: JP165.2, MCU5.14
D49: JP176.1, U15.13
D50: TP90.TP, U15.12
D51: R90.1, U15.1
D52: R86.1, U15.2
D53: TP92.TP, U15.9
D55: TP91.TP, U15.11
D56: JP176.2, U15.14
D57: JP181.1, U18.13
D58: TP106.TP, U18.12
D59: R100.1, U18.1
D60: R96.1, U18.2
D61: TP108.TP, U18.9
D63: TP107.TP, U18.11
D64: JP181.2, U18.14
D65: JP287.1, MCU9.13
D66: MCU9.12, TP114.P$1
D67: MCU9.32, TP115.1
D68: MCU9.1, R110.1
D69: MCU9.2, R106.1
D70: MCU9.9, TP111.P$1
D71: MCU9.10, TP112.P$1
D72: MCU9.11, TP113.P$1
D73: JP211.1, MCU6.13
D74: MCU6.12, TP130.P$1
D75: MCU6.32, TP131.1
D76: MCU6.1, R120.1
D77: MCU6.2, R116.1
D78: MCU6.9, TP127.P$1
D79: MCU6.10, TP128.P$1
D80: MCU6.11, TP129.P$1
D81: JP211.2, MCU6.14
D82: JP238.1, MCU7.13
D83: MCU7.12, TP139.P$1
D84: MCU7.32, TP140.1
D85: MCU7.1, R130.1
D86: MCU7.2, R126.1
D87: MCU7.9, TP136.P$1
D88: MCU7.10, TP137.P$1
D89: MCU7.11, TP138.P$1
D90: JP238.2, MCU7.14
D91: JP265.1, MCU8.13
D92: MCU8.12, TP148.P$1
D93: MCU8.32, TP149.1
D94: MCU8.1, R140.1
D95: MCU8.2, R136.1
D96: MCU8.9, TP145.P$1
D97: MCU8.10, TP146.P$1
D98: MCU8.11, TP147.P$1
D99: JP265.2, MCU8.14
D100: JP287.2, MCU9.14
D101: JP294.1, U25.13
D102: TP158.TP, U25.12
D103: R150.1, U25.1
D104: R146.1, U25.2
D105: TP160.TP, U25.9
D107: TP159.TP, U25.11
D108: JP294.2, U25.14
DTR: C2.2, JP10.1
DTR1: C16.2, JP33.1
DTR2: C27.2, JP62.1
DTR3: C38.2, JP91.1
DTR4: C49.2, JP120.1
DTR5: C60.2, JP149.1
DTR6: C104.2, JP193.1
DTR7: C112.2, JP220.1
DTR8: C120.2, JP247.1
DTR9: C93.2, JP188.1
DTR29: C132.2, TP172.TP
GND: C1.1, C3.1, C4.2, C5.2, C6.2, C7.2, C8.2, C9.2, C10.2, C11.2, D1.C, JP2.1, JP3.1, JP5.1, JP6.1, JP16.1, JP22.GND1, JP22.SHIELD1, JP22.SHIELD2, JP22.SHIELD3, JP25.1, LDO.1, MCU.3, MCU.5, MCU.21, Q1.2, Q2.2, R3.1, R5.1, R7.1, R9.1, TP3.P$1, TP4.TP, TP9.P$1, TP12.TP, U1.1, U1.9, U1.11, U1.18, U2.2
GND1: C12.2, C13.1, C14.1, C15.2, C17.2, C18.2, C19.2, C20.2, C21.2, C22.2, D3.C, JP7.1, JP39.1, JP47.1, JP48.1, JP53.1, JP57.1, JP58.GND1, JP58.SHIELD1, JP58.SHIELD2, JP58.SHIELD3, LDO1.1, MCU1.3, MCU1.5, MCU1.21, Q3.2, Q4.2, R17.1, R19.1, R21.1, R28.1, TP20.P$1, TP21.P$1, TP24.TP, TP26.TP, U3.2, U4.1, U4.9, U4.11, U4.18
GND2: C23.2, C24.1, C25.1, C26.2, C28.2, C29.2, C30.2, C31.2, C32.2, C33.2, D5.C, JP59.1, JP68.1, JP76.1, JP77.1, JP82.1, JP86.1, JP87.GND1, JP87.SHIELD1, JP87.SHIELD2, JP87.SHIELD3, LDO2.1, MCU2.3, MCU2.5, MCU2.21, Q5.2, Q6.2, R31.1, R33.1, R35.1, R42.1, TP33.P$1, TP34.P$1, TP37.TP, TP39.TP, U5.2, U6.1, U6.9, U6.11, U6.18
GND3: C34.2, C35.1, C36.1, C37.2, C39.2, C40.2, C41.2, C42.2, C43.2, C44.2, D7.C, JP88.1, JP97.1, JP105.1, JP106.1, JP111.1, JP115.1, JP116.GND1, JP116.SHIELD1, JP116.SHIELD2, JP116.SHIELD3, LDO3.1, MCU3.3, MCU3.5, MCU3.21, Q7.2, Q8.2, R45.1, R47.1, R49.1, R56.1, TP46.P$1, TP47.P$1, TP50.TP, TP52.TP, U7.2, U8.1, U8.9, U8.11, U8.18
GND4: C45.2, C46.1, C47.1, C48.2, C50.2, C51.2, C52.2, C53.2, C54.2, C55.2, D9.C, JP117.1, JP126.1, JP134.1, JP135.1, JP140.1, JP144.1, JP145.GND1, JP145.SHIELD1, JP145.SHIELD2, JP145.SHIELD3, LDO4.1, MCU4.3, MCU4.5, MCU4.21, Q9.2, Q10.2, R59.1, R61.1, R63.1, R70.1, TP59.P$1, TP60.P$1, TP63.TP, TP65.TP, U9.2, U10.1, U10.9, U10.11, U10.18
GND5: C56.2, C57.1, C58.1, C59.2, C61.2, C62.2, C63.2, C64.2, C65.2, C66.2, D11.C, JP146.1, JP155.1, JP163.1, JP164.1, JP169.1, JP173.1, JP174.GND1, JP174.SHIELD1, JP174.SHIELD2, JP174.SHIELD3, LDO5.1, MCU5.3, MCU5.5, MCU5.21, Q11.2, Q12.2, R73.1, R75.1, R77.1, R84.1, TP72.P$1, TP73.P$1, TP76.TP, TP78.TP, U11.2, U12.1, U12.9, U12.11, U12.18
GND6: C67.2, C68.1, C69.1, C70.2, C71.2, C72.2, C73.2, C74.2, C75.2, C76.2, C77.1, D13.C, JP175.1, JP179.GND1, JP179.SHIELD1, JP179.SHIELD2, JP179.SHIELD3, LDO6.1, Q13.2, Q14.2, R87.1, R89.1, R91.1, TP80.P$1, TP82.TP, TP93.TP, TP94.TP, U13.2, U14.1, U14.9, U14.11, U14.18, U15.3, U15.5, U15.21, U15.PAD
GND7: C78.2, C79.1, C80.1, C81.2, C82.2, C83.2, C84.2, C85.2, C86.2, C87.2, C88.1, D14.C, JP180.1, JP184.GND1, JP184.SHIELD1, JP184.SHIELD2, JP184.SHIELD3, LDO7.1, Q15.2, Q16.2, R97.1, R99.1, R101.1, TP96.P$1, TP98.TP, TP109.TP, TP110.TP, U16.2, U17.1, U17.9, U17.11, U17.18, U18.3, U18.5, U18.21, U18.PAD
GND8: C89.2, C90.1, C91.1, C92.2, C94.2, C95.2, C96.2, D15.C, JP185.1, JP275.1, JP284.1, JP285.1, JP286.1, JP290.2, JP292.GND, JP292.MT1, JP292.MT2, LDO8.1, MCU9.3, MCU9.5, MCU9.21, Q17.2, Q18.2, R107.1, R109.1, R111.1, R114.1, TP117.P$1, TP119.P$1, U19.2
GND9: C100.2, C101.1, C102.1, C103.2, C105.2, C106.2, C107.2, D16.C, JP190.1, JP199.1, JP208.1, JP209.1, JP210.1, JP214.2, JP216.GND, JP216.MT1, JP216.MT2, LDO9.1, MCU6.3, MCU6.5, MCU6.21, Q19.2, Q20.2, R117.1, R119.1, R121.1, R124.1, TP133.P$1, TP135.P$1, U22.2
GND10: C108.2, C109.1, C110.1, C111.2, C113.2, C114.2, C115.2, D17.C, JP217.1, JP226.1, JP235.1, JP236.1, JP237.1, JP241.2, JP243.GND, JP243.MT1, JP243.MT2, LDO10.1, MCU7.3, MCU7.5, MCU7.21, Q21.2, Q22.2, R127.1, R129.1, R131.1, R134.1, TP142.P$1, TP144.P$1, U23.2
GND11: C116.2, C117.1, C118.1, C119.2, C121.2, C122.2, C123.2, D18.C, JP244.1, JP253.1, JP262.1, JP263.1, JP264.1, JP268.2, JP270.GND, JP270.MT1, JP270.MT2, LDO11.1, MCU8.3, MCU8.5, MCU8.21, Q23.2, Q24.2, R137.1, R139.1, R141.1, R144.1, TP151.P$1, TP153.P$1, U24.2
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

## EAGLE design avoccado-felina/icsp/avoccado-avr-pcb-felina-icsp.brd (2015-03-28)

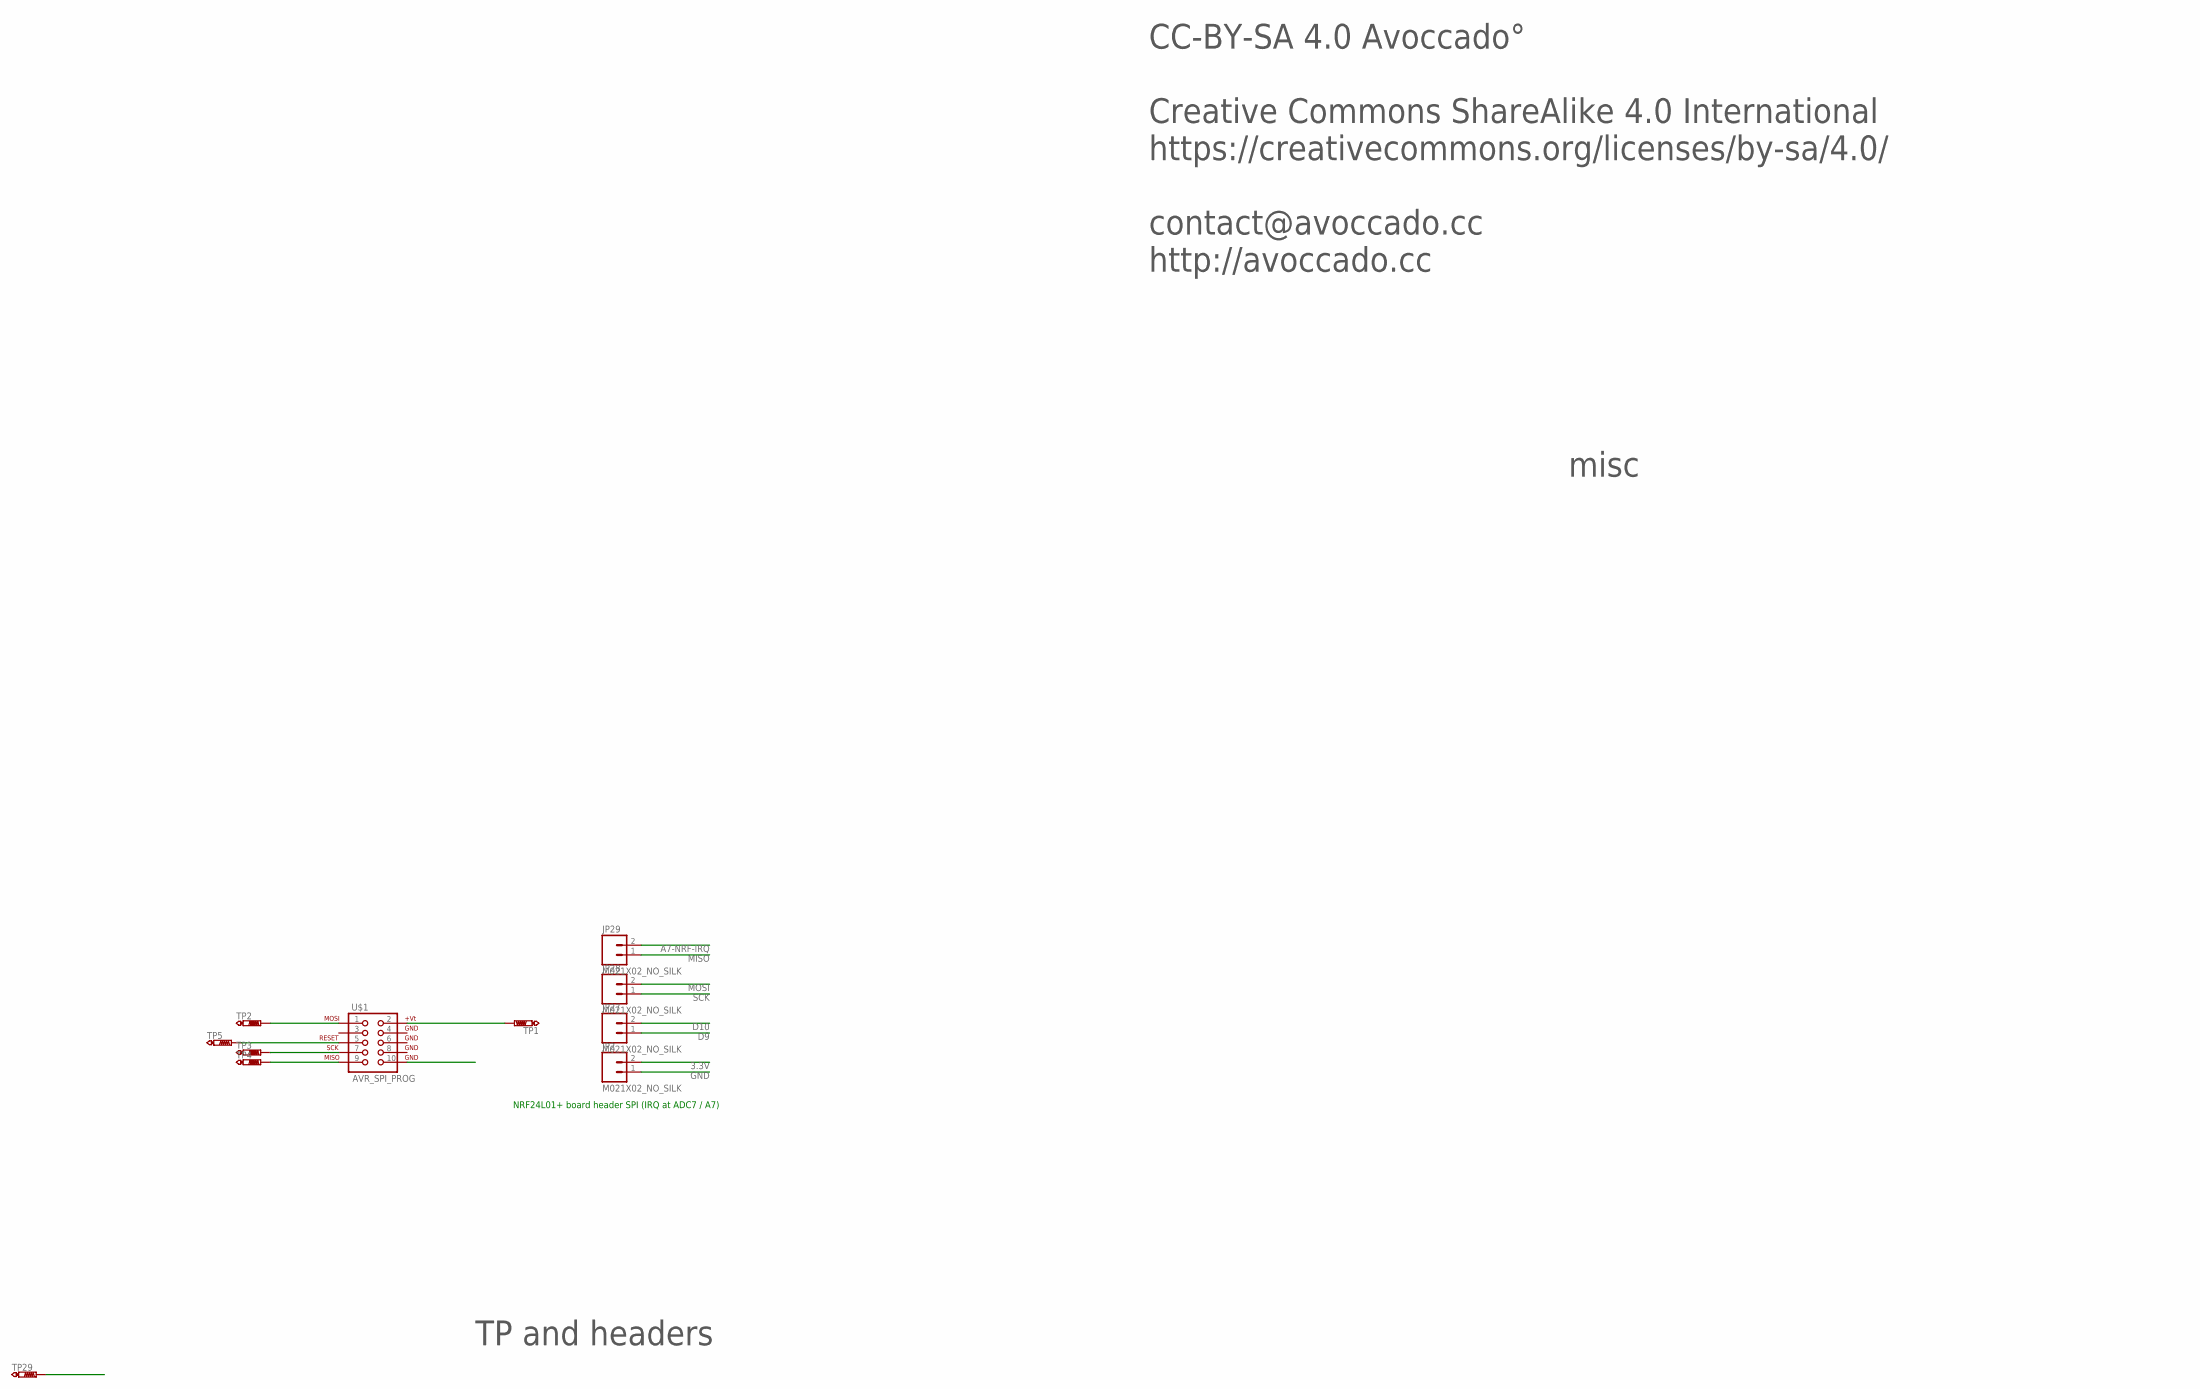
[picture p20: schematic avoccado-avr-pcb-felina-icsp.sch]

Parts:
JP2, JP27, JP28, JP29: M021X02_NO_SILK; 1X02_NO_SILK
TP1, TP2, TP3, TP4, TP5, TP29: PTR1PAD1-13; P1-13
U$1: AVR_SPI_PROG; AVR_ICSP

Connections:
3.3V: JP2.2, TP1.TP, U$1.2
A7-NRF-IRQ: JP29.2
D9: JP27.1
D10: JP27.2
GND: JP2.1, TP29.TP, U$1.10
MISO: JP29.1, TP4.TP, U$1.9
MOSI: JP28.2, TP2.TP, U$1.1
RESET: TP5.TP, U$1.5
SCK: JP28.1, TP3.TP, U$1.7

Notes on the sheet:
NRF24L01+ board header SPI (IRQ at ADC7 / A7)
TP and headers
misc
CC-BY-SA 4.0 Avoccado° Creative Commons ShareAlike 4.0 International https://creativecommons.org/licenses/by-sa/4.0/ contact@avoccado.cc http://avoccado.cc

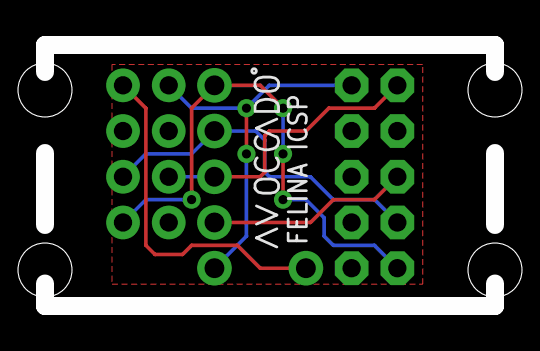
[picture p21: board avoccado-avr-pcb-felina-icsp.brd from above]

Board: 2 copper layers, 25.0 x 14.5 mm, 11 parts (1 on the bottom side), 6 nets.

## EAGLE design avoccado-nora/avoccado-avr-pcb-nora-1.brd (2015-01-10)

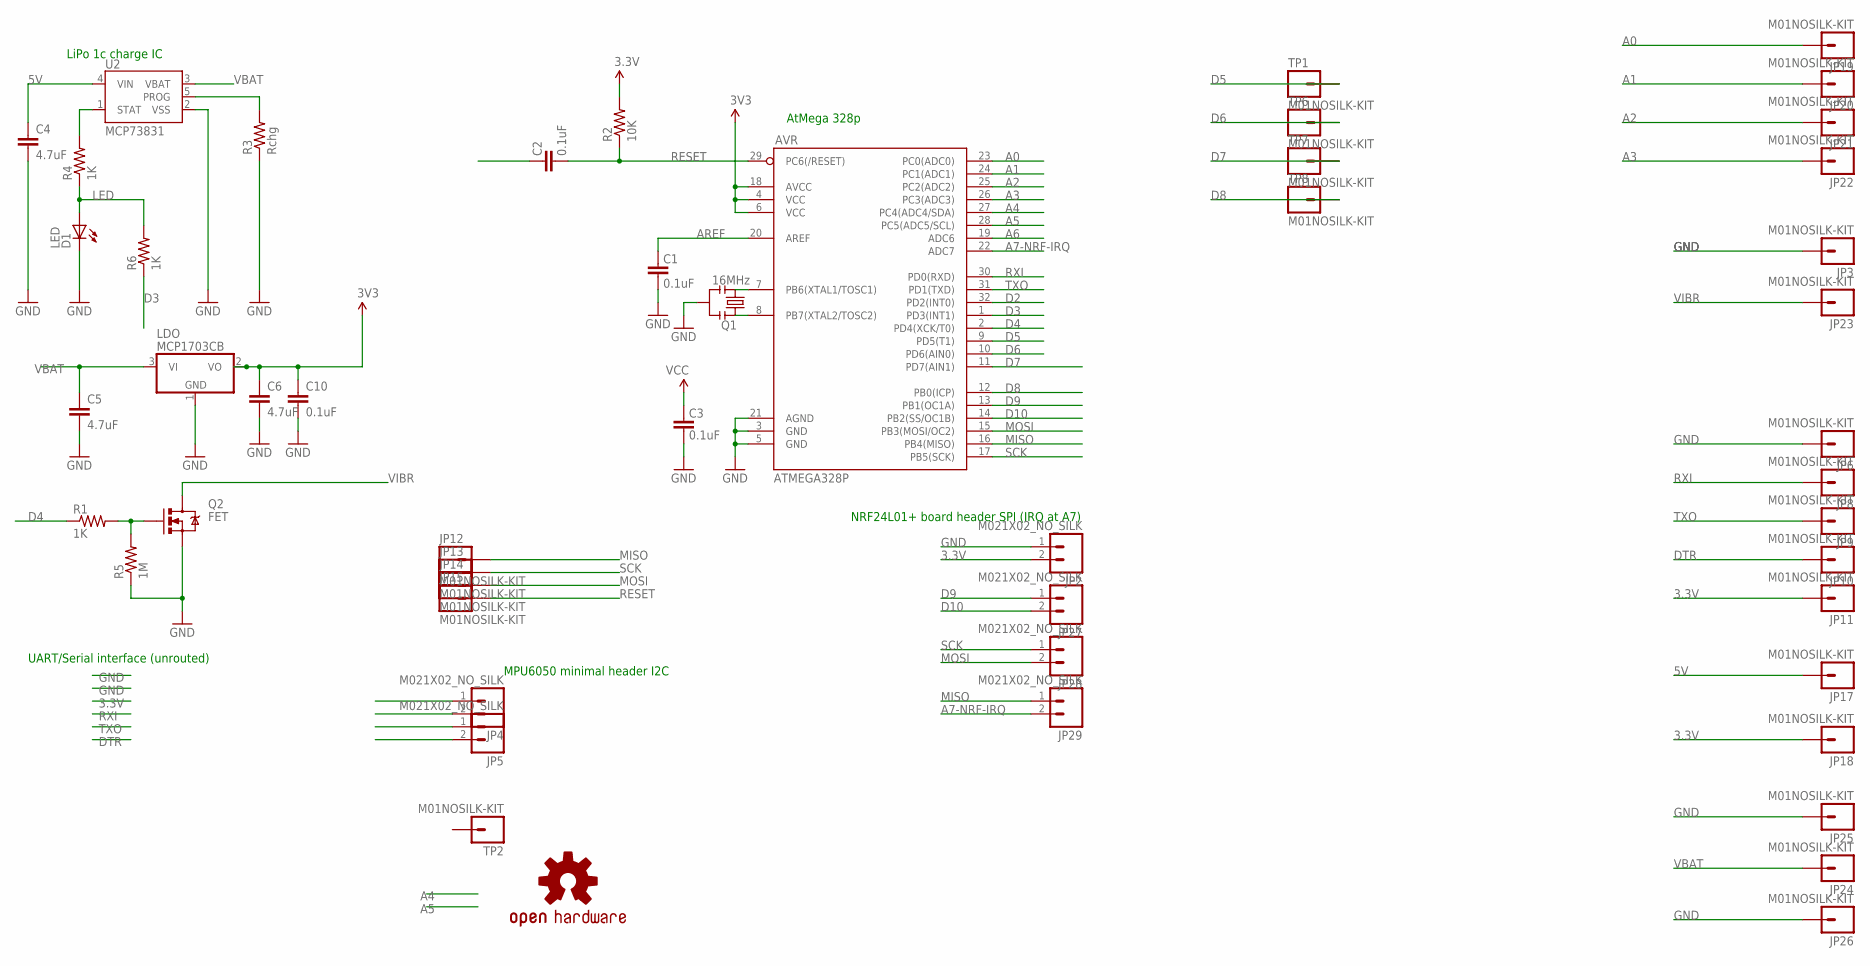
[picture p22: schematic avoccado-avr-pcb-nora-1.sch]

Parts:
AVR: ATMEGA328P; TQFP32-08
C1, C2, C3, C10: 0.1uF; C0402
C4, C5, C6: 4.7uF; 0603-CAP
D1: LED; LED-0603
JP2, JP4, JP5, JP27, JP28, JP29: M021X02_NO_SILK; 1X02_NO_SILK
JP3, JP6, JP8, JP9, JP10, JP11, JP12, JP13, JP14, JP15, JP17, JP18, JP19, JP20, JP21, JP22, JP23, JP24, JP25, JP26: M01NOSILK-KIT; 1X01NS-KIT
LDO: MCP1703CB; SOT23
LOGO1: OSHW-LOGOS; OSHW-LOGO-S
Q1: 16MHz; RESONATOR-SMD
Q2: FET; SOT323
R1, R4, R6: 1K; 0603-RES
R2: 10K; 0603-RES
R3: Rchg; 0603-RES
R5: 1M; 0603-RES
TP1, TP2, TP6, TP7, TP8: M01NOSILK-KIT; 1X01NS-KIT
U2: MCP73831; SOT23-5

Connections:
3.3V: AVR.4 (VCC), AVR.6 (VCC), AVR.18 (AVCC), C3.2, C6.1, C10.1, JP2.2, JP4.1, JP11.1, JP18.1, LDO.2 (VO), R2.2
5V: C4.1, JP17.1, U2.4 (VIN)
A0: AVR.23 (PC0(ADC0)), JP19.1
A1: AVR.24 (PC1(ADC1)), JP20.1
A2: AVR.25 (PC2(ADC2)), JP21.1
A3: AVR.26 (PC3(ADC3)), JP22.1
A4: AVR.27 (PC4(ADC4/SDA)), JP5.2
A5: AVR.28 (PC5(ADC5/SCL)), JP5.1
A6: AVR.19 (ADC6)
A7-NRF-IRQ: AVR.22 (ADC7), JP29.2
AREF: AVR.20 (AREF), C1.2
CHG-PROG: R3.2, U2.5 (PROG)
D2: AVR.32 (PD2(INT0))
D3: AVR.1 (PD3(INT1)), R6.1
D4: AVR.2 (PD4(XCK/T0)), R1.1
D5: AVR.9 (PD5(T1)), TP1.1
D6: AVR.10 (PD6(AIN0)), TP6.1
D7: AVR.11 (PD7(AIN1)), TP7.1
D8: AVR.12 (PB0(ICP)), TP8.1
D9: AVR.13 (PB1(OC1A)), JP27.1
D10: AVR.14 (PB2(SS/OC1B)), JP27.2
DTR: C2.2, JP10.1
GND: AVR.3 (GND), AVR.5 (GND), AVR.21 (AGND), C1.1, C3.1, C4.2, C5.2, C6.2, C10.2, D1.C, JP2.1, JP3.1, JP4.2, JP6.1, JP25.1, JP26.1, LDO.1 (GND), Q1.2, Q2.2 (S), R3.1, R5.1, U2.2 (VSS)
LED: D1.A, R4.1, R6.2
MISO: AVR.16 (PB4(MISO)), JP12.1, JP29.1
MOSI: AVR.15 (PB3(MOSI/OC2)), JP14.1, JP28.2
unnamed: AVR.8 (PB7(XTAL2/TOSC2)), Q1.1
unnamed: AVR.7 (PB6(XTAL1/TOSC1)), Q1.3
unnamed: Q2.1 (G), R1.2, R5.2
RESET: AVR.29 (PC6(/RESET)), C2.1, JP15.1, R2.1
RXI: AVR.30 (PD0(RXD)), JP8.1
SCK: AVR.17 (PB5(SCK)), JP13.1, JP28.1
SOC: R4.2, U2.1 (STAT)
TXO: AVR.31 (PD1(TXD)), JP9.1
VBAT: C5.1, JP24.1, LDO.3 (VI), U2.3 (VBAT)
VIBR: JP23.1, Q2.3 (D)

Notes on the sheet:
NRF24L01+ board header SPI (IRQ at A7)
MPU6050 minimal header I2C
AtMega 328p
LiPo 1c charge IC
UART/Serial interface (unrouted)

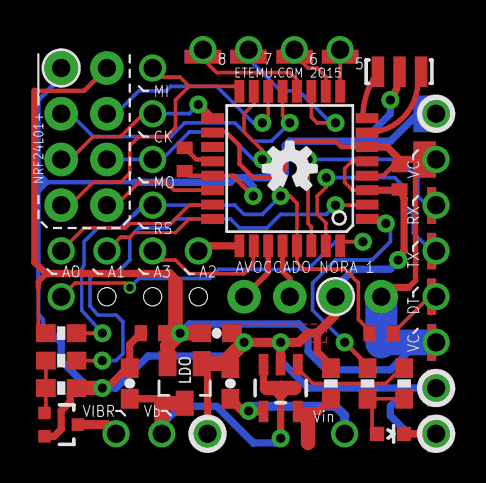
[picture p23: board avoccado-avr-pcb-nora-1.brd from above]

Board: 2 copper layers, 52 parts (1 on the bottom side), 34 nets.

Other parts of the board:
LOGO2: OSHW-LOGOS; OSHW-LOGO-S

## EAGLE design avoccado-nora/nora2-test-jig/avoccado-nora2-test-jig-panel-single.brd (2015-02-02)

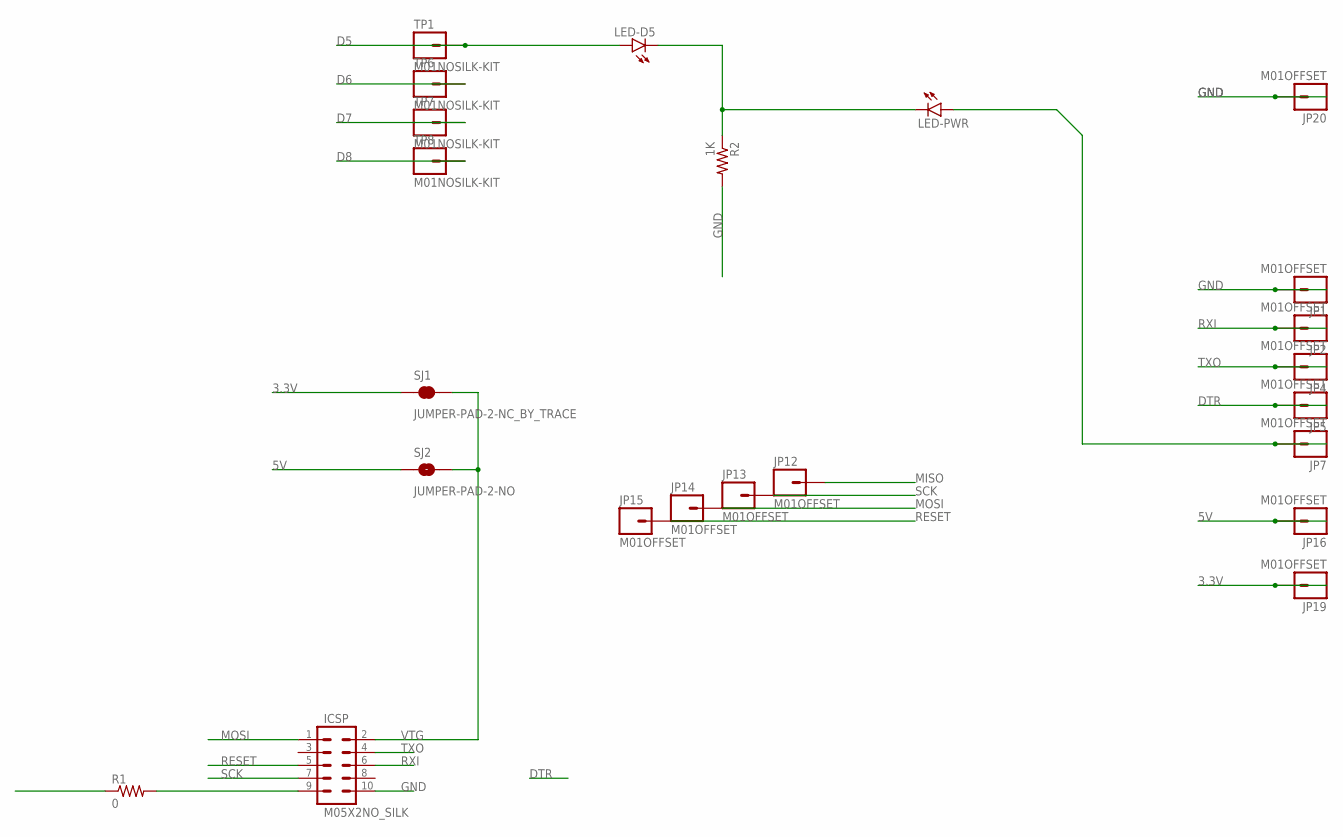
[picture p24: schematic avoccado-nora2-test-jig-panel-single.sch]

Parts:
ICSP: M05X2NO_SILK; 2X5_NOSILK
JP1, JP2, JP4, JP5, JP7, JP12, JP13, JP14, JP15, JP16, JP19, JP20: M01OFFSET; 1X01_OFFSET
LED-D5: LED0603; LED-0603
LED-PWR: LED0603; LED-0603
R1: 0; 1206
R2: 1K; 0603-RES
SJ1: JUMPER-PAD-2-NC_BY_TRACE; PAD-JUMPER-2-NC_BY_TRACE_YES_SILK
SJ2: JUMPER-PAD-2-NO; PAD-JUMPER-2-NO_NO_SILK
TP1, TP6, TP7, TP8: M01NOSILK-KIT; 1X01NS-KIT

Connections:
3.3V: JP19.1, SJ1.1
5V: JP16.1, SJ2.1
D5: LED-D5.A, TP1.1
D6: TP6.1
D7: TP7.1
D8: TP8.1
DTR: JP5.1
GND: ICSP.10, JP1.1, JP20.1, R2.2
MISO: JP12.1, R1.1
MISO1: ICSP.9, R1.2
MOSI: ICSP.1, JP14.1
unnamed: LED-D5.C, LED-PWR.C, R2.1
unnamed: JP7.1, LED-PWR.A
RESET: ICSP.5, JP15.1
RXI: ICSP.6, JP2.1
SCK: ICSP.7, JP13.1
TXO: ICSP.4, JP4.1
VTG: ICSP.2, SJ1.2, SJ2.2

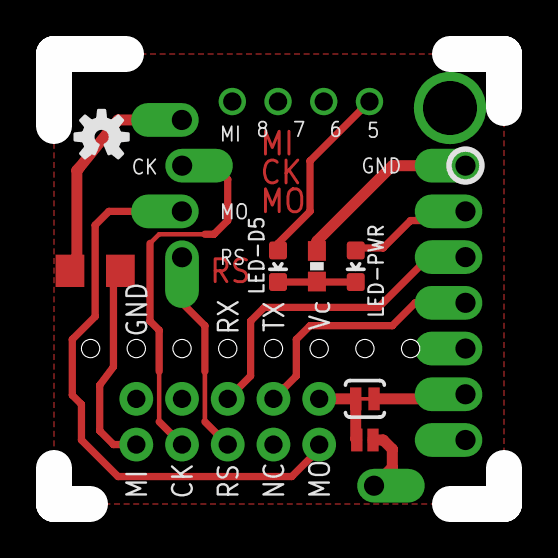
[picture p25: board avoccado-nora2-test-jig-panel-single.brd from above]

Board: 2 copper layers, 25.0 x 25.0 mm, 24 parts (1 on the bottom side), 14 nets.

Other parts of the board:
LOGO2: OSHW-LOGOS; OSHW-LOGO-S

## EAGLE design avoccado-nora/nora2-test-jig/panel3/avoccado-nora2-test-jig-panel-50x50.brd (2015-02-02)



Board: 2 copper layers, 60.0 x 60.0 mm, 96 parts (4 on the bottom side), 53 nets.

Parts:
ICSP, ICSP1, ICSP2, ICSP3: M05X2NO_SILK; 2X5_NOSILK
JP1, JP2, JP3, JP4, JP5, JP6, JP7, JP8, JP9, JP10, JP11, JP12, JP13, JP14, JP15, JP16, JP17, JP18, JP19, JP20, JP21, JP22, JP23, JP24, JP25, JP26, JP27, JP28, JP29, JP30, JP31, JP32, JP33, JP34, JP35, JP36, JP37, JP38, JP39, JP40, JP41, JP42, JP43, JP44, JP45, JP46, JP47, JP48: M01OFFSET; 1X01_OFFSET
LED-D1, LED-D2, LED-D3, LED-D5: LED-0603
LED-PWR, LED-PWR1, LED-PWR2, LED-PWR3: LED-0603
LOGO1, LOGO2, LOGO3, LOGO4: OSHW-LOGOS; OSHW-LOGO-S
R1, R3, R5, R7: 0; 1206
R2, R4, R6, R8: 1K; 0603-RES
SJ1, SJ3, SJ5, SJ7: JUMPER-PAD-2-NC_BY_TRACE; PAD-JUMPER-2-NC_BY_TRACE_YES_SILK
SJ2, SJ4, SJ6, SJ8: JUMPER-PAD-2-NO; PAD-JUMPER-2-NO_NO_SILK
TP1, TP2, TP3, TP4, TP5, TP6, TP7, TP8, TP9, TP10, TP11, TP12, TP13, TP14, TP15, TP16: M01NOSILK-KIT; 1X01NS-KIT

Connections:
3.3V: JP19.1, SJ1.1
3.3V1: JP23.1, SJ3.1
3.3V2: JP35.1, SJ5.1
3.3V3: JP47.1, SJ7.1
5V: JP16.1, SJ2.1
5V1: JP22.1, SJ4.1
5V2: JP34.1, SJ6.1
5V3: JP46.1, SJ8.1
D2: LED-D1.A, TP2.1
D5: LED-D5.A, TP1.1
D10: LED-D2.A, TP9.1
D14: LED-D3.A, TP13.1
GND: ICSP.10, ICSP1.10, ICSP2.10, ICSP3.10, JP1.1, JP10.1, JP20.1, JP24.1, JP29.1, JP36.1, JP41.1, JP48.1, R2.2, R4.2, R6.2, R8.2
MISO: JP12.1, R1.1
MISO1: ICSP.9, R1.2
MISO2: JP3.1, R3.1
MISO3: ICSP1.9, R3.2
MISO4: JP25.1, R5.1
MISO5: ICSP2.9, R5.2
MISO6: JP37.1, R7.1
MISO7: ICSP3.9, R7.2
MOSI: ICSP.1, JP14.1
MOSI1: ICSP1.1, JP8.1
MOSI2: ICSP2.1, JP27.1
MOSI3: ICSP3.1, JP39.1
unnamed: LED-D5.C, LED-PWR.C, R2.1
unnamed: JP7.1, LED-PWR.A
unnamed: LED-D1.C, LED-PWR1.C, R4.1
unnamed: JP21.1, LED-PWR1.A
unnamed: LED-D2.C, LED-PWR2.C, R6.1
unnamed: JP33.1, LED-PWR2.A
unnamed: LED-D3.C, LED-PWR3.C, R8.1
unnamed: JP45.1, LED-PWR3.A
RESET: ICSP.5, JP15.1
RESET1: ICSP1.5, JP9.1
RESET2: ICSP2.5, JP28.1
RESET3: ICSP3.5, JP40.1
RXI: ICSP.6, JP2.1
RXI1: ICSP1.6, JP11.1
RXI2: ICSP2.6, JP30.1
RXI3: ICSP3.6, JP42.1
SCK: ICSP.7, JP13.1
SCK1: ICSP1.7, JP6.1
SCK2: ICSP2.7, JP26.1
SCK3: ICSP3.7, JP38.1
TXO: ICSP.4, JP4.1
TXO1: ICSP1.4, JP17.1
TXO2: ICSP2.4, JP31.1
TXO3: ICSP3.4, JP43.1
VTG: ICSP.2, SJ1.2, SJ2.2
VTG1: ICSP1.2, SJ3.2, SJ4.2
VTG2: ICSP2.2, SJ5.2, SJ6.2
VTG3: ICSP3.2, SJ7.2, SJ8.2

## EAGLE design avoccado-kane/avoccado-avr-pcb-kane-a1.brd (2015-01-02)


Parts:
AVR: ATMEGA328P; TQFP32-08
C1, C3, C10: 0.1uF; C0402
C2, C5: 4.7uF; 0603-CAP
JP1, JP2, JP3, JP4, JP5, JP6, JP7, JP8, JP9, JP10, JP11, JP12, JP13, JP14, JP15, JP16, JP17, JP18, JP19, JP20, JP21, JP22, JP23, JP24, JP25: M01SMD; LUXEON-PAD
LDO1: MCP1703CB; SOT23
MPU6050: M041X04_NO_SILK; 1X04_NO_SILK
NRF24: M04X2; 2X4
Q1: 16MHz; RESONATOR-SMD
R2: 10K; 0603-RES

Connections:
3V3: AVR.4 (VCC), AVR.6 (VCC), AVR.18 (AVCC), C3.2, C5.1, C10.1, JP1.P$1, JP8.P$1, LDO1.2 (VO), MPU6050.1, NRF24.2, R2.2
A0: AVR.23 (PC0(ADC0)), JP9.P$1
A1: AVR.24 (PC1(ADC1)), JP10.P$1
A2: AVR.25 (PC2(ADC2)), JP11.P$1
A3: AVR.26 (PC3(ADC3)), JP3.P$1
A4: AVR.27 (PC4(ADC4/SDA)), MPU6050.4
A5: AVR.28 (PC5(ADC5/SCL)), MPU6050.3
A6: AVR.19 (ADC6)
A7: AVR.22 (ADC7)
AREF: AVR.20 (AREF), C1.2
D2: AVR.32 (PD2(INT0)), JP15.P$1
D3: AVR.1 (PD3(INT1)), JP13.P$1
D4: AVR.2 (PD4(XCK/T0)), JP14.P$1
D5: AVR.9 (PD5(T1))
D6: AVR.10 (PD6(AIN0))
D7: AVR.11 (PD7(AIN1))
D8: AVR.12 (PB0(ICP))
D9: AVR.13 (PB1(OC1A)), NRF24.3
D10: AVR.14 (PB2(SS/OC1B)), NRF24.4
GND: AVR.3 (GND), AVR.5 (GND), AVR.21 (AGND), C1.1, C2.2, C3.1, C5.2, C10.2, JP7.P$1, JP12.P$1, JP16.P$1, JP17.P$1, JP18.P$1, JP19.P$1, JP20.P$1, JP21.P$1, JP22.P$1, JP23.P$1, LDO1.1 (GND), MPU6050.2, NRF24.1, Q1.2
MISO: AVR.16 (PB4(MISO)), NRF24.7
MOSI: AVR.15 (PB3(MOSI/OC2)), NRF24.6
unnamed: AVR.8 (PB7(XTAL2/TOSC2)), Q1.1
unnamed: AVR.7 (PB6(XTAL1/TOSC1)), Q1.3
RESET: AVR.29 (PC6(/RESET)), JP5.P$1, JP25.P$1, R2.1
RXI: AVR.30 (PD0(RXD)), JP2.P$1
SCK: AVR.17 (PB5(SCK)), NRF24.5
TXO: AVR.31 (PD1(TXD)), JP4.P$1
VBAT: C2.1, JP6.P$1, JP24.P$1, LDO1.3 (VI)

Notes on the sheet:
NRF24L01+ board header SPI (IRQ NC)
MPU6050 minimal header I2C (IRQ NC)
AtMega 328p
UART/Serial interface (unrouted)



Board: 2 copper layers, 17.5 x 21.3 mm, 36 parts (17 on the bottom side), 23 nets.

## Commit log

2014-11-28 initial push from local repo
    [avoccado-avr-pcb.brd, avoccado-avr-pcb.sch]
2014-11-30 add n-chan LL mosfet for vibrator
    [avoccado-avr-pcb.brd, avoccado-avr-pcb.sch]
2014-11-30 add A6 and A7 analog inputs
    [avoccado-avr-pcb.brd, avoccado-avr-pcb.sch]
2014-11-30 fix fragmented move
    [avoccado-avr-pcb.brd, avoccado-avr-pcb.sch]
2014-12-01 wip change to SMD headers
    [avoccado-avr-pcb.brd, avoccado-avr-pcb.sch]
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2014-12-03 exchanged THT pin rows for custom SMD pads
    [avoccado-avr-pcb.brd, avoccado-avr-pcb.sch]
2014-12-04 squeezed the headers together to make the PCB even thinner
    [avoccado-avr-pcb.brd, avoccado-avr-pcb.sch]
2014-12-04 add NRF24 header wip
    [avoccado-avr-pcb.brd, avoccado-avr-pcb.sch]
2014-12-06 reroute NRF24 header with bottom layer, add MPU6050 satellite board
    [avoccado-avr-pcb.brd, avoccado-avr-pcb.sch]
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2014-12-06 white silkscreen fills at GND pads
    [avoccado-avr-pcb.brd, avoccado-avr-pcb.sch]
2014-12-06 add QFN package for MCU wip
    [avoccado-avr-pcb.brd, avoccado-avr-pcb.sch]
2014-12-06 moved Xtal to make room for vias
    [avoccado-avr-pcb.brd, avoccado-avr-pcb.sch]
2014-12-07 charge indicator wired to MCU
    [avoccado-avr-pcb.brd, avoccado-avr-pcb.sch]
2014-12-07 reroute bottom header, reduce airwires
    [avoccado-avr-pcb.brd, avoccado-avr-pcb.sch]
2014-12-07 minor corrections
    [avoccado-avr-pcb.brd]
2014-12-07 reroute GND layer, ditch pins 2&3
    [avoccado-avr-pcb.brd, avoccado-avr-pcb.sch]
2014-12-07 corrected DRC errors, mostly spacing
    [avoccado-avr-pcb.brd, avoccado-avr-pcb.sch]
2014-12-09 increase board size to 19x42
    [avoccado-avr-pcb.brd, avoccado-avr-pcb.sch]
2014-12-09 change MPU6050 locked header to straight one
    [avoccado-avr-pcb.brd, avoccado-avr-pcb.sch]
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2014-12-10 3D renderings and micro version started
    [avoccado-avr-pcb-micro-a1.brd, avoccado-avr-pcb-micro-a1.sch]
2014-12-11 render gerber files and update micro-a1
    [20140912avoccado-avr-pcb-100x100panel.brd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]
2014-12-11 finish avoccado-avr-pcb-kane micro version
    [avoccado-avr-pcb-kane-a1-panel.brd, avoccado-avr-pcb-kane-a1.brd, avoccado-avr-pcb-kane-a1.sch]
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2015-01-02 start new 1 sq inch PCB fork 'yolandi'
    [avoccado-avr-pcb-kane-a1.brd, avoccado-avr-pcb-yolandi.brd, avoccado-avr-pcb-yolandi.sch]
2015-01-03 routing yolandi
    added DTR-reset latch circuit with 0.1uF C
    [avoccado-avr-pcb-yolandi.brd, avoccado-avr-pcb-yolandi.sch]
2015-01-03 routing yolandi, lower part with PDU
    [avoccado-avr-pcb-yolandi.brd, avoccado-avr-pcb-yolandi.sch]
2015-01-03 routing the buffered load output
    [avoccado-avr-pcb-yolandi.brd, avoccado-avr-pcb-yolandi.sch]
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2015-01-03 change pkg of NRF24 header to round pins
    [avoccado-avr-pcb-yolandi.brd, avoccado-avr-pcb-yolandi.sch]
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2015-01-04 clear silkscreen which is outside of dimension layer
    [avoccado-avr-pcb-yolandi.brd]
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2015-01-05 draft: panelized yolandi to 100x100mm
    [avoccado-avr-pcb-yolandi-panel.brd, avoccado-avr-pcb-yolandi-panel.sch]
2015-01-06 Nora: new PCB with plated half holes for surface mounting
    [avoccado-avr-pcb-nora.brd, avoccado-avr-pcb-nora.sch, avoccado-avr-pcb-yolandi-panel.brd]
2015-01-06 fix silkscreen on nora
    [avoccado-nora-panel.brd, avoccado-nora-panel.sch]
2015-01-07 add rectangles at plated half holes
    [avoccado-avr-pcb-nora.brd, avoccado-nora-panel.brd]
2015-01-10 panelized nora to 50x50mm²
    [avoccado-avr-pcb-nora.brd, avoccado-avr-pcb-yolandi-panel.brd, avoccado-nora-panel-teardropped.brd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]
2015-01-14 panelized nora2, rendered gerbers
    [avoccado-avr-pcb-nora-2-panel-test.brd, avoccado-avr-pcb-nora-2.brd, avoccado-avr-pcb-nora-2.sch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]
2015-01-17 create test jig for nora
    [avoccado-nora-test-jig.brd, avoccado-nora-test-jig.sch]
2015-01-17 switch layer for ICSP 2x5 header to bottom
    [avoccado-nora-test-jig.brd, avoccado-nora-test-jig.sch]
2015-01-17 ditch DTR line at ICSP header
    [avoccado-nora-test-jig.brd, avoccado-nora-test-jig.sch]
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2015-01-18 test alignment of test jig panel
    [avoccado-nora-test-jig_25x25.brd, avoccado-nora-test-jig_25x25.sch, avoccado-nora2-test-jig-panel-100x100.brd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]
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2015-01-28 Initial commit for Avoccado° Faye
    new: battery voltage sensing
    [avoccado-avr-pcb-faye.brd, avoccado-avr-pcb-faye.sch]
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2015-01-28 redesign lower half of Faye
    [avoccado-avr-pcb-faye.brd]
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2015-01-29 all signals routed to spec
    TODO: snap to grid, silkscreen
    [avoccado-avr-pcb-faye.brd, avoccado-avr-pcb-faye.sch]
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2015-02-02 bigger pads for test jig, g-code for solder stencils
    [avoccado-avr-pcb-faye.brd, avoccado-avr-pcb-nora-1.brd, avoccado-avr-pcb-nora-1.sch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]
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2015-02-27 Faye: adjusted Rs, new PCB: Felina
    Felina is a larger PCB with the MPU6050 on board instead of a breakout
    board.
    [avoccado-avr-pcb-felina.brd, avoccado-avr-pcb-felina.sch]
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2015-02-28 route reset pullup
    [avoccado-avr-pcb-felina.brd, avoccado-avr-pcb-felina.sch]
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2015-03-01 fix DRC errors
    [avoccado-avr-pcb-felina.brd, avoccado-avr-pcb-felina.sch]
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2015-03-08 no airwires left, added 5V USB power LED
    [avoccado-avr-pcb-felina-screwholes.brd, avoccado-avr-pcb-felina-screwholes.sch]
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2015-03-08 add redundant fiducials near mounting holes, reverse LED and R
    [avoccado-avr-pcb-felina-screwholes.brd, avoccado-avr-pcb-felina-screwholes.sch]
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2015-03-11 Introducing Avoccado° Gin: Nano version, QFN only, not obeing placement restrictions, board dimensions less than one NRF24L01+ module.
    [avoccado-avr-gin.brd, avoccado-avr-gin.sch]
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2015-03-25 Finish silkscreen with a wide A° instead of pin declarations
    [avoccado-avr-gin.brd, avoccado-avr-gin.sch]
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2015-03-26 DRC check with 6mil / 6mil, silkscreen touchup
    [avoccado-avr-gin.brd, avoccado-avr-gin.sch]
2015-03-26 Felina: remove screw mounts, Gin: prepare to panelize
    [avoccado-avr-gin-panel.brd, avoccado-avr-gin-panel.sch, avoccado-avr-pcb-felina.brd]
2015-03-26 fix big silkscreen logo
    [avoccado-avr-pcb-felina.brd]
2015-03-26 layout panel with Gin, Felina, Faye at 100x100mm²
    [avoccado-avr-gin.brd, avoccado-panel-felina-faye-gin.brd, avoccado-panel-felina-faye-gin.sch]
2015-03-27 Gin: fix mirrored silkscreen on bottom layer
    [avoccado-avr-gin.brd]
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

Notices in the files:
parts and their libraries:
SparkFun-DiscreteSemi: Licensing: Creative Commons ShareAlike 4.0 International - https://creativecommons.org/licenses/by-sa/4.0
